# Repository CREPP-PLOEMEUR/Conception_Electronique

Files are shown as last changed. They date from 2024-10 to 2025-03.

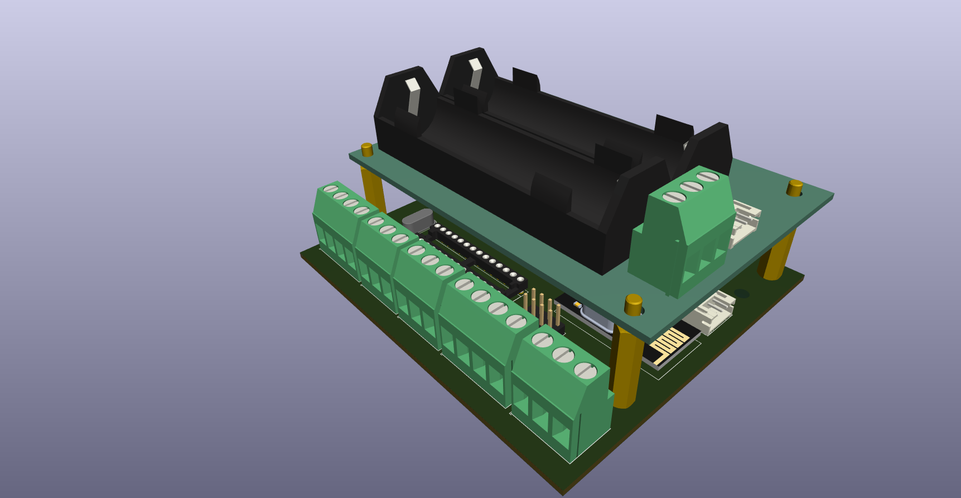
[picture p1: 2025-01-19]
Base.png

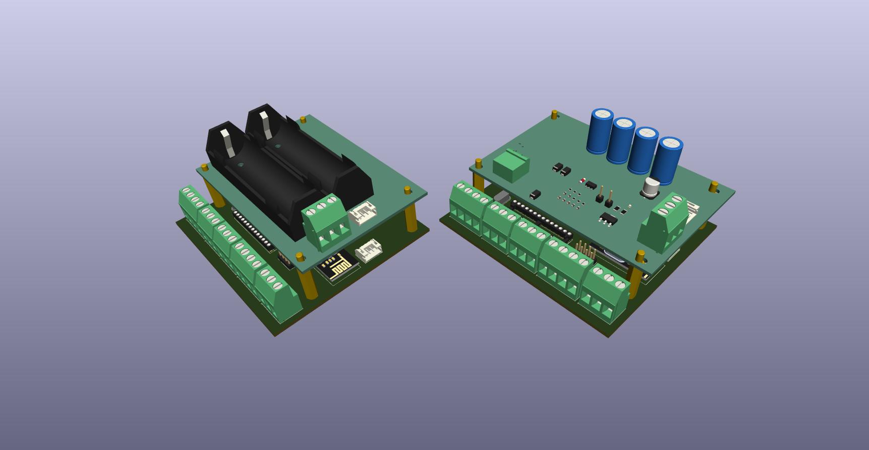
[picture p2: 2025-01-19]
Base.jpg

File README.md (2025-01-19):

# Conception_Electronique
Le répertoire avec les sources de l'atelier Conception Electronique

## Installation de Kicad

La version de Kicad sera la version 8.X : 

## Projets 2024-2025

Pour cette année, les projets souhaités sont :

- Une station météo
- Une carte de développement pour microcontrôleur 

- Cahier des charges
- Schématique
- Commande de matériel
- Affectation des empreintes
- Routage
- Génération du dossier de fabrication
- Montage
- Debug

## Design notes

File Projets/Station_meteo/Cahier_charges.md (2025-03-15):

# Capteurs

- Kit de capteurs sur Internet 

    - Température     (BME280)  -
    - pression          
    - Humidité
    - Vitesse du vent
    - Direction du vent 
    - Pluviométrie (volume)
    - Position GPS - NEO-M6
    - RTC - DS3231

- Connecteurs : 

- USB-C
- LED 
- Bouton Reset

- Connecteur 5 points
- Connecteur 4 points
- Connecteur 3 points
- Connecteur 2 points

Liste du matériel : 

- Borniers 5.08mm
- Microcontrolleur ATMEGA328-PU
- Transistor FDS4559

Options :  - Ensoleillement (GUVA-S12SD)
           - (Détecteur de particule fine (Co2))

- Type de connecteurs capteurs : bornier 5.08mm à vis 

- Intégration de l'antenne du NRF24 (support mécanique à prévoir si module avec ampli)
- doubler eventuellement les cellules lithium

- Mesure du vent :

Mesure du vent toutes les 10 minutes (réveil périodique) puis envoi toutes les 30 minutes
- Potentiomètre pour période de réveil
- Envoi de données "exceptionnelles" lors de rafale

- Envoi de la valeur moyenne et de la rafale

Pour la rafale, mesure avec un compteur à creuser et à designer :

Dimensionnement du pluviomètre  (mesure de volume et de pluie par jour)

Max : 95 mm/h de précipitation

# Alimentation

-> Autonome : 
    - supercondensateurs -> GEstion energie
    - batterie lithium  -> GEstion energie

# Fonctions

- Envoi de données par la station -> traitement des données ailleurs 
- Connecteur d'alimentation de debug : 
    - Shield avec OLED, USB et LED

- Alimentation et panneau solaire : Olivier et Michel H

- Capteurs : Michel O (& Nicolas) Eric (Olivier)

- Microcontroleur et NFR24 : Nicolas & Robin P.

- protocole de communication : Nathalie - (Philippe P)

- 

- PCB : Michel O. (Patrice G). - Philippe C.

- Programmation : Nicolas

- Centralisation des achats et matériel : Guy et Patrick

Faire un point tous les 15 jours à la louche

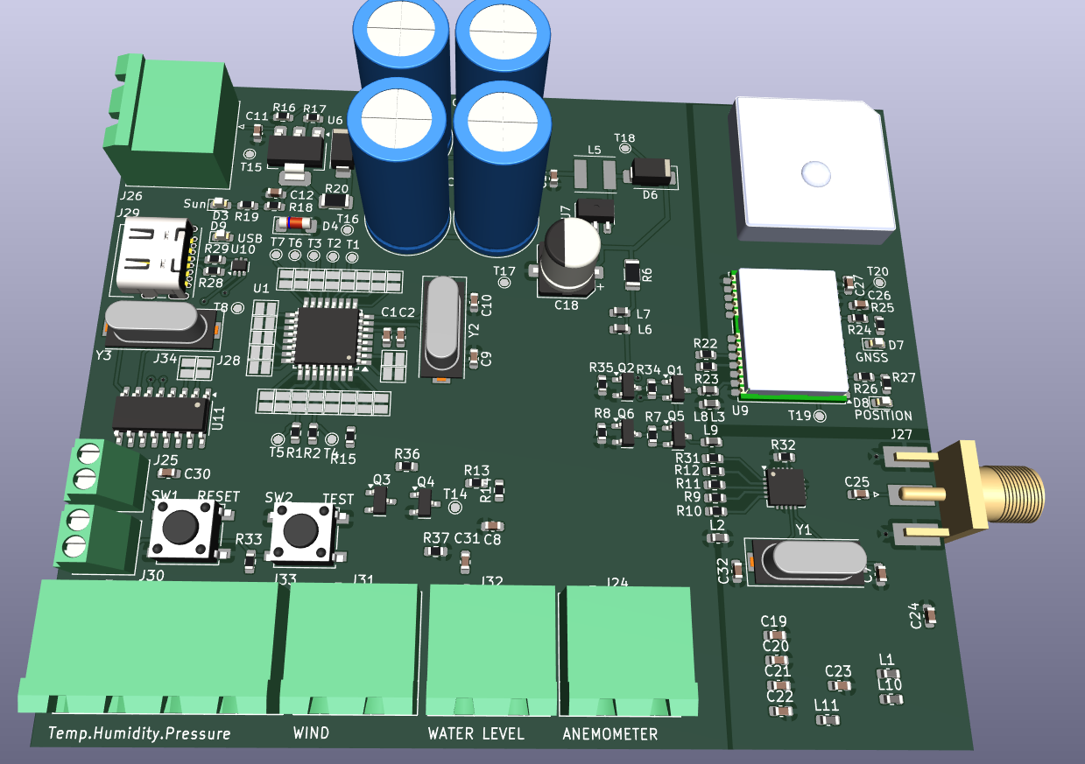
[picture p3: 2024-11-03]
Projets/Station_meteo/PCB/V0_Prototype/img/Proto.png

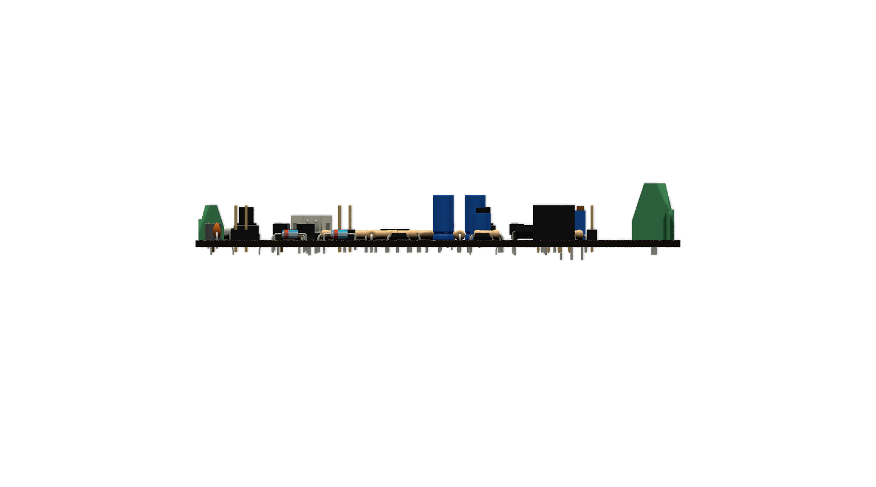
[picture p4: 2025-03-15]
Projets/Station_meteo/PCB/V1_THT/Base/3D_Gallery/Side.png

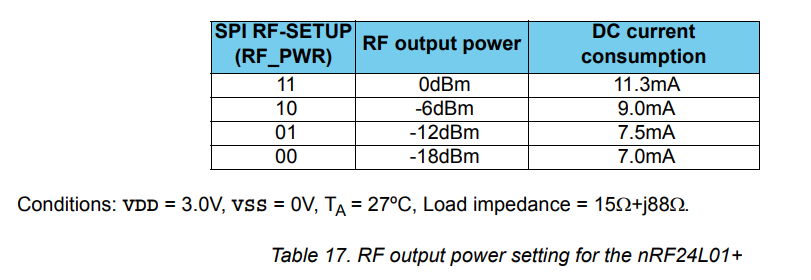
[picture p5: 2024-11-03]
Projets/Station_meteo/Consumption.png

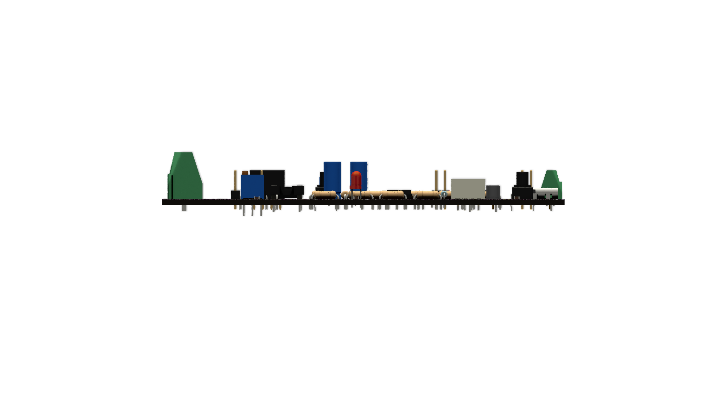
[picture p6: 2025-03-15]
Projets/Station_meteo/PCB/V1_THT/Base/3D_Gallery/Front.png

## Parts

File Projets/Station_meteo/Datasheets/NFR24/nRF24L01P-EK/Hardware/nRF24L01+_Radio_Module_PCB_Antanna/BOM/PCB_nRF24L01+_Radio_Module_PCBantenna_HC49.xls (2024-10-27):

Part | Designator | Footprint | Description
22pF | C1 | 0402 | NPO, +/- 5%, 50V
22pF | C2 | 0402 | NPO, +/- 5%, 50V
2.2nF | C3 | 0402 | X7R, +/- 10%, 50V
4.7pF | C4 | 0402 | NPO, +/- 0.25 pF, 50V
1.5pF | C5 | 0402 | NPO, +/- 0.1 pF, 50V
1.0pF | C6 | 0402 | NPO, +/- 0.1 pF, 50V
33nF | C7 | 0402 | X7R, +/- 10%, 50V
1nF | C8 | 0402 | X7R, +/- 10%, 50V
10nF | C9 | 0402 | X7R, +/- 10%, 50V
CON8 | J1 | 2,54mm pitch
8.2nH | L1 | 0402 | chip inductor +/- 5%
2.7nH | L2 | 0402 | chip inductor +/- 5%
3.9nH | L3 | 0402 | chip inductor +/- 5%
1M | R1 | 0402 | +/-5% (or better)
22K | R2 | 0402 | +/- 1 %
nRF24L01+ | U1 | QFN20L/5x5
16MHz | X1 | HC49 | Total tolerence +/-60ppm, CL=12pF

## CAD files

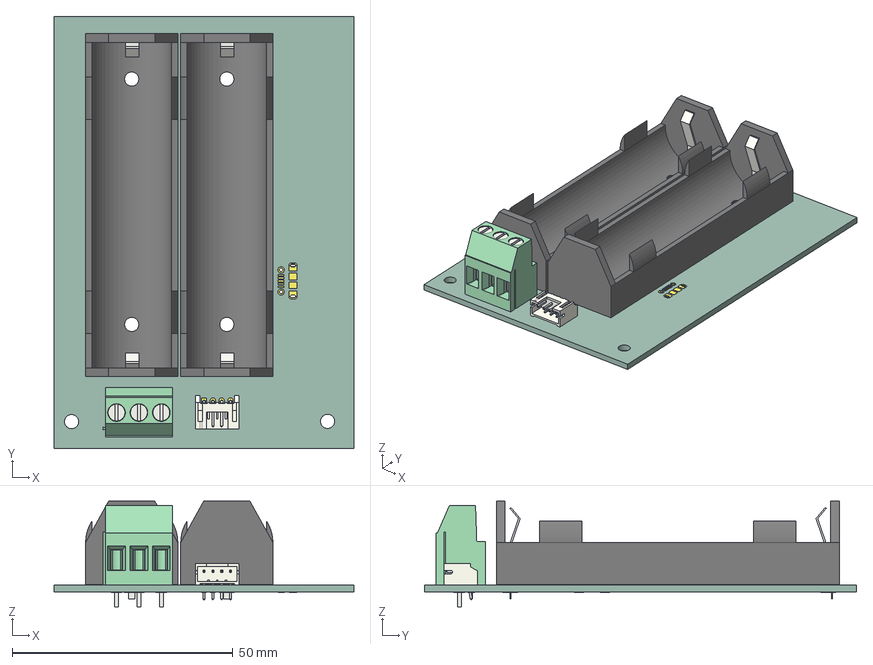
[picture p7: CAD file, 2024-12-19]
Projets/Station_meteo/PCB/V1_THT/Shield_Lithium/Tracker.step
67.9 x 97.9 x 24.0 mm
MPD_BH_18650_PC2 x 2
JST_S4B_PH_K
TerminalBlock_Phoenix_MKDS_3_3_508_1x03_P508mm_Horizontal
Shield_Lithium_pad_1
Shield_Lithium_pad_2
Shield_Lithium_pad_3
Shield_Lithium_pad_4
Shield_Lithium_pad_5
Shield_Lithium_pad_6
Shield_Lithium_pad_7
Shield_Lithium_pad_8
Shield_Lithium_pad_9
Shield_Lithium_pad_10
Shield_Lithium_pad_11
Shield_Lithium_pad_12
Shield_Lithium_pad_13
Shield_Lithium_pad_14
Shield_Lithium_pad_15
Shield_Lithium_pad_16
Shield_Lithium_pad_17
Shield_Lithium_pad_18
Shield_Lithium_pad_19
Shield_Lithium_pad_20
Shield_Lithium_pad_21
Shield_Lithium_pad_22
Shield_Lithium_pad_23
Shield_Lithium_pad_24
Shield_Lithium_pad_25
Shield_Lithium_pad_26
Shield_Lithium_pad_27
Shield_Lithium_pad_28
Shield_Lithium_pad_29
Shield_Lithium_pad_30
Shield_Lithium_pad_31
Shield_Lithium_pad_32
Shield_Lithium_pad_33
Shield_Lithium_pad_34
Shield_Lithium_pad_35
Shield_Lithium_pad_36
Shield_Lithium_pad_37
Shield_Lithium_pad_38
Shield_Lithium_pad_39
Shield_Lithium_pad_40
Shield_Lithium_pad_41
Shield_Lithium_pad_42
Shield_Lithium_pad_43
Shield_Lithium_pad_44
Shield_Lithium_pad_45
Shield_Lithium_pad_46
Shield_Lithium_pad_47
Shield_Lithium_pad_48
Shield_Lithium_pad_49
Shield_Lithium_pad_50
Shield_Lithium_pad_51
Shield_Lithium_pad_52
Shield_Lithium_pad_53
Shield_Lithium_pad_54
Shield_Lithium_pad_55
Shield_Lithium_pad_56
Shield_Lithium_pad_57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

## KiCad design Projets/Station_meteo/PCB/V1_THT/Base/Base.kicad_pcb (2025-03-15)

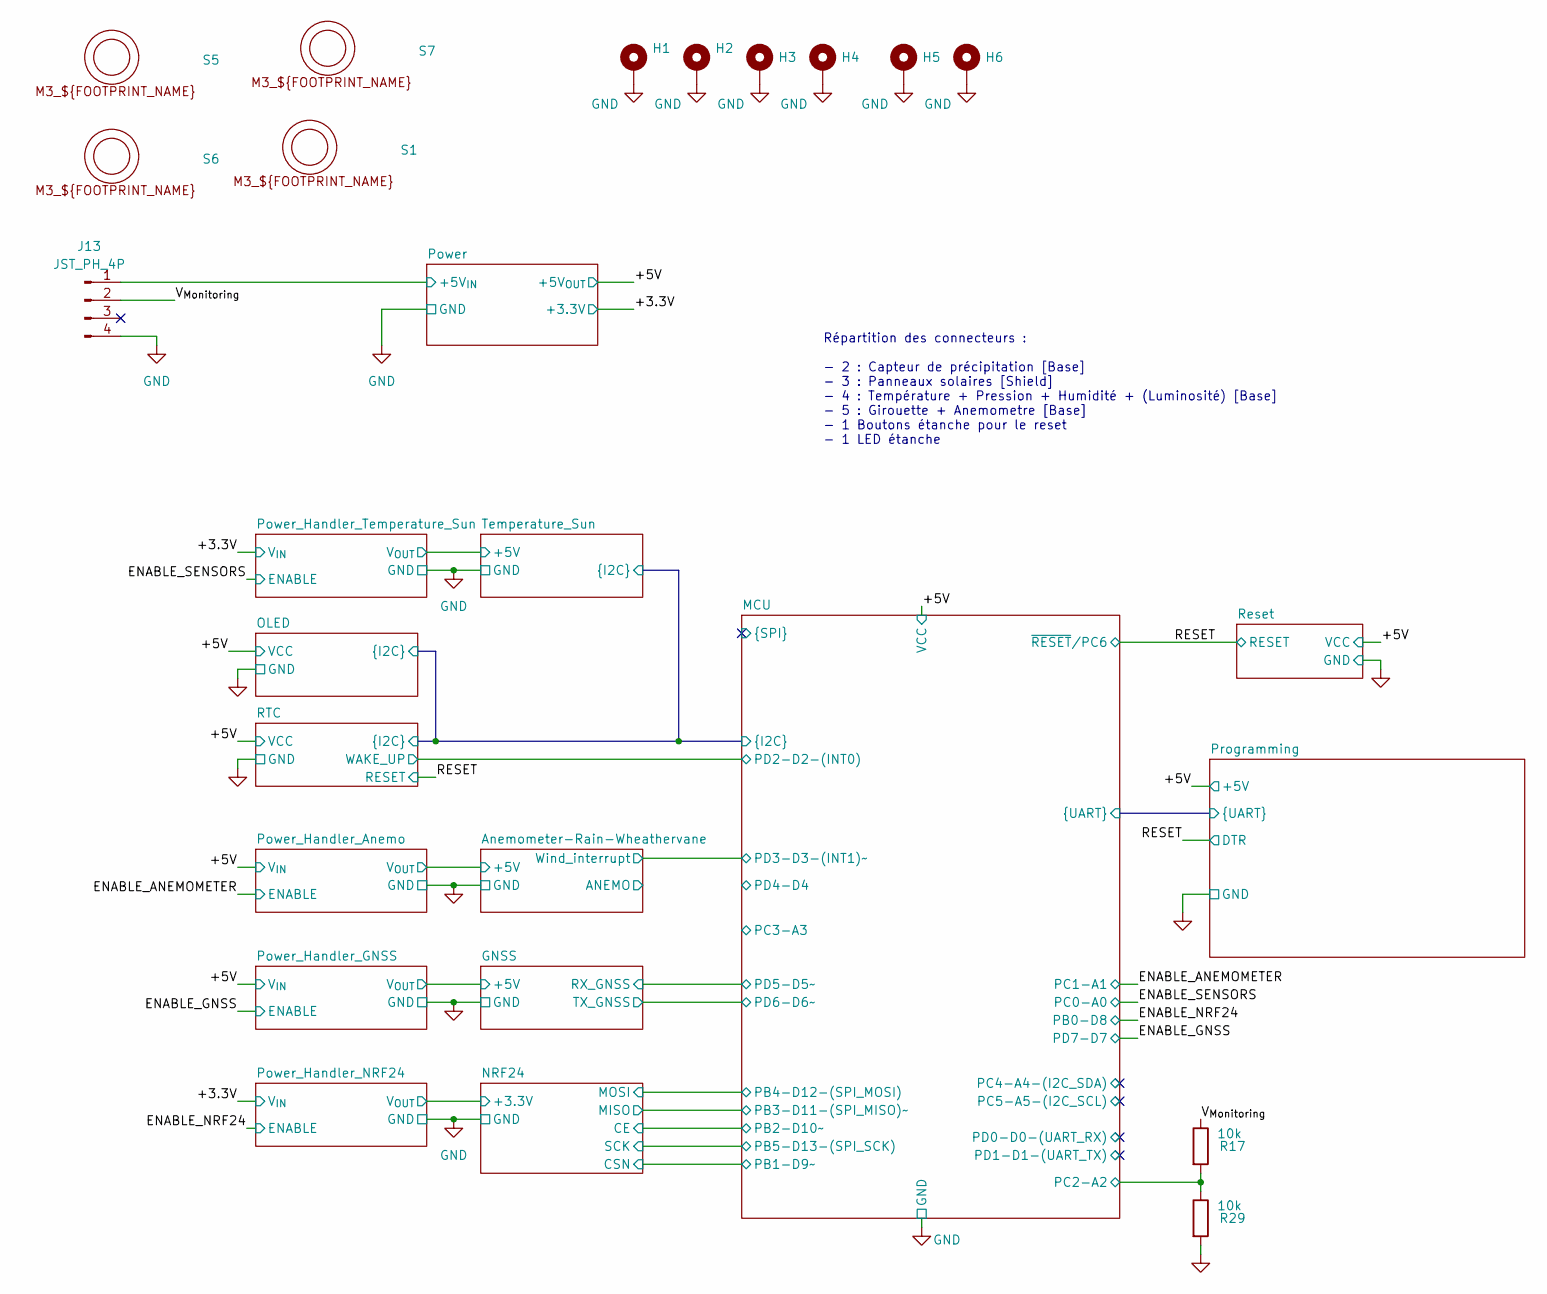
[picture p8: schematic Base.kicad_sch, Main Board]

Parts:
H1, H2, H3, H4, H5, H6: MountingHole_Pad; MountingHole_3.2mm_M3
J13: JST_PH_4P; JST_PH_B4B-PH-K_1x04_P2.00mm_Vertical
R17, R29: 10k; R_Axial_DIN0207_L6.3mm_D2.5mm_P7.62mm_Horizontal
S1, S5, S6, S7: Spacer_M3_MF_05mm

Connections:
/MCU/PC2-A2: R17.2, R29.1; also elsewhere on the board
/Power/+5V_{IN}: J13.1; also elsewhere on the board
/V_{Monitoring}: J13.2, R17.1
GND: H1.1, H2.1, H3.1, H4.1, H5.1, H6.1, J13.4, R29.2; also elsewhere on the board

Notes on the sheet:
Répartition des connecteurs : - 2 : Capteur de précipitation [Base] - 3 : Panneaux solaires [Shield] - 4 : Température + Pression + Humidité + (Luminosité) [Base] - 5 : Girouette + Anemometre [Base] - 1 Boutons étanche pour le reset - 1 LED étanche

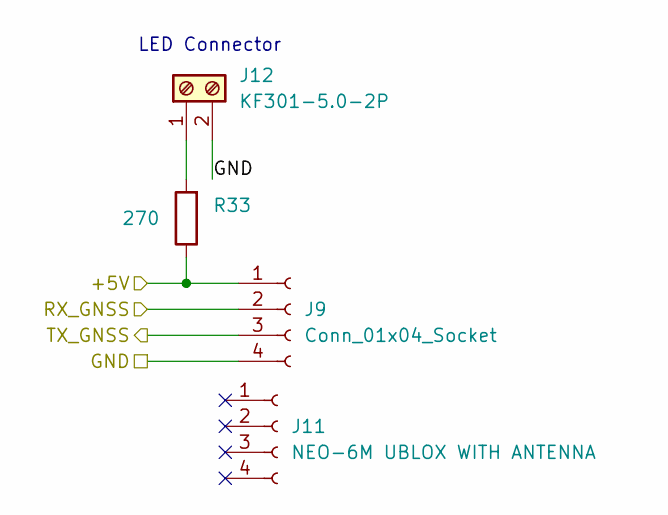
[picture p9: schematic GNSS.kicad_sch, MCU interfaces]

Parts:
J9: Conn_01x04_Socket; PinSocket_1x04_P2.54mm_Vertical
J11: NEO-6M UBLOX WITH ANTENNA; PinSocket_1x04_P2.54mm_Vertical
J12: KF301-5.0-2P; TerminalBlock_Phoenix_MKDS-1,5-2_1x02_P5.00mm_Horizontal
R33: 270; R_Axial_DIN0207_L6.3mm_D2.5mm_P7.62mm_Horizontal

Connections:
/GNSS/+5V: J9.1, R33.1; also elsewhere on the board
/GNSS/RX_GNSS: J9.2; also elsewhere on the board
/GNSS/TX_GNSS: J9.3; also elsewhere on the board
GND: J9.4, J12.2; also elsewhere on the board
unnamed: J12.1, R33.2

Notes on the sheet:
LED Connector

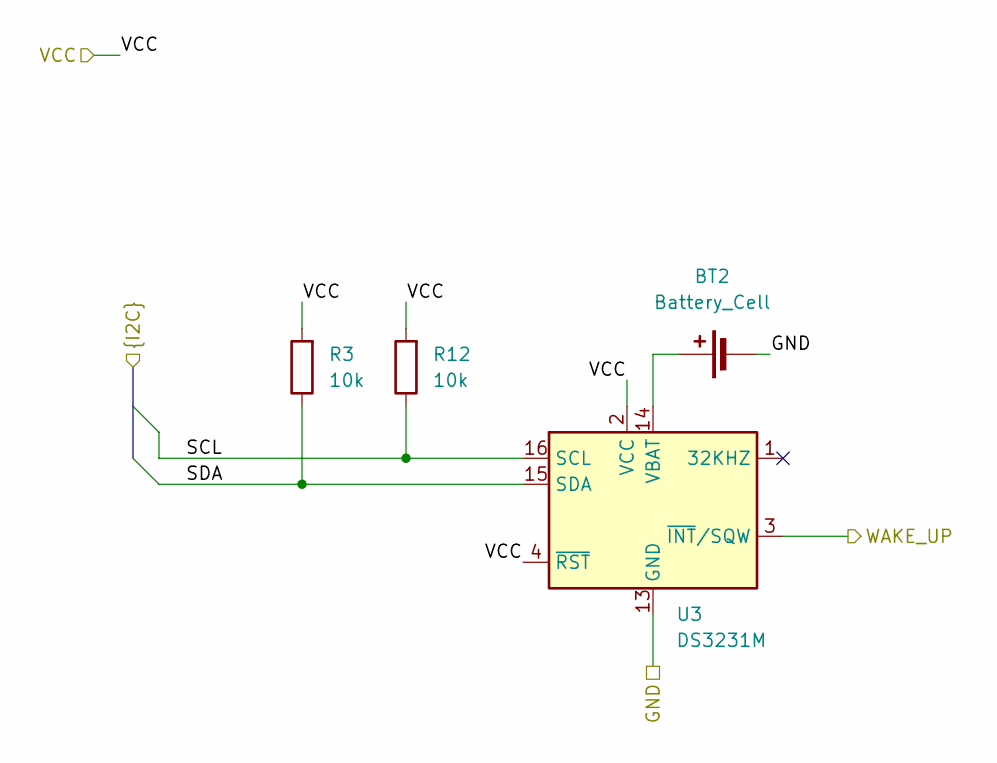
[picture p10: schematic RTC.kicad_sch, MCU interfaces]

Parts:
BT2: Battery_Cell; MPD_BC501SM-TR
R3, R12: 10k; R_Axial_DIN0207_L6.3mm_D2.5mm_P7.62mm_Horizontal
U3: DS3231M; SOIC-16W_7.5x10.3mm_P1.27mm

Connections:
/MCU/PD2-D2-(INT0): U3.3 (~INT/SQW); also elsewhere on the board
/MCU/SCL: R12.1, U3.16 (SCL); also elsewhere on the board
/MCU/SDA: R3.1, U3.15 (SDA); also elsewhere on the board
GND: U3.5 (GND), U3.6 (GND), U3.7 (GND), U3.8 (GND), U3.9 (GND), U3.10 (GND), U3.11 (GND), U3.12 (GND), U3.13 (GND); also elsewhere on the board
unnamed: BT2.1 (+), U3.14 (VBAT)
unnamed 75: R3.1; also elsewhere on the board
unnamed 76: R12.1; also elsewhere on the board
unnamed 77: R3.2, R12.2; also elsewhere on the board

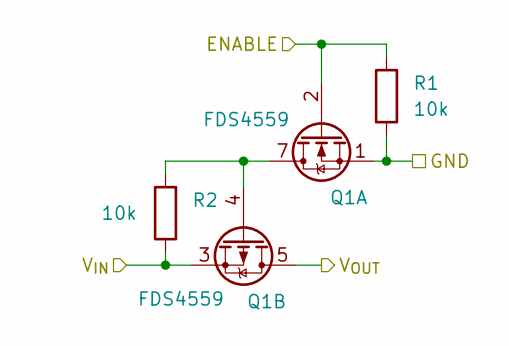
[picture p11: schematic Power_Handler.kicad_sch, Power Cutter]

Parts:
Q1: FDS4559; SOIC-8_3.9x4.9mm_P1.27mm
R1, R2: 10k; R_Axial_DIN0207_L6.3mm_D2.5mm_P7.62mm_Horizontal

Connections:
/Anemometer-Rain-Wheathervane/+5V: Q1.5 (D), Q1.6 (D); also elsewhere on the board
/ENABLE_ANEMOMETER: Q1.2 (G), R1.2; also elsewhere on the board
GND: Q1.1 (S), R1.1; also elsewhere on the board
unnamed: Q1.4 (G), Q1.7 (D), Q1.8 (D), R2.2

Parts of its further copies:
Q2, Q3, Q4: FDS4559; SOIC-8_3.9x4.9mm_P1.27mm
R14, R15, R16, R18, R19, R28: 10k; R_Axial_DIN0207_L6.3mm_D2.5mm_P7.62mm_Horizontal

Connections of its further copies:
/+3.3V: Q2.3 (1), Q4.3 (1), R18.1, R28.1; also elsewhere on the board
/ENABLE_GNSS: Q3.2 (G), R15.2; also elsewhere on the board
/ENABLE_NRF24: Q2.2 (G), R14.2; also elsewhere on the board
/ENABLE_SENSORS: Q4.2 (G), R16.2; also elsewhere on the board
/GNSS/+5V: Q3.5 (D), Q3.6 (D); also elsewhere on the board
/NRF24/+3.3V: Q2.5 (D), Q2.6 (D); also elsewhere on the board
/Power_Handler_Temperature_Sun/V_{OUT}: Q4.5 (D), Q4.6 (D)
GND: Q2.1 (S), Q3.1 (S), Q4.1 (S), R14.1, R15.1, R16.1; also elsewhere on the board
unnamed: Q2.4 (G), Q2.7 (D), Q2.8 (D), R18.2
unnamed: Q3.4 (G), Q3.7 (D), Q3.8 (D), R19.2
unnamed: Q4.4 (G), Q4.7 (D), Q4.8 (D), R28.2

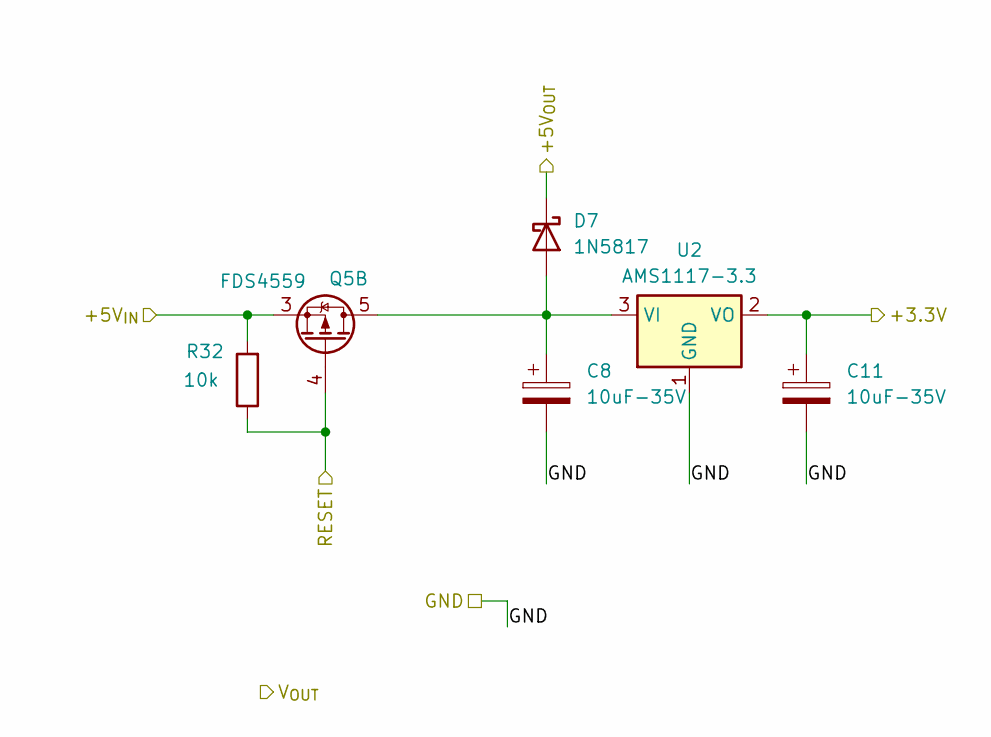
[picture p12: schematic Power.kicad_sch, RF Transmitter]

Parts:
C8, C11: 10uF-35V; C_Radial_D5.0mm_H11.0mm_P2.00mm
D7: 1N5817; D_DO-41_SOD81_P10.16mm_Horizontal
Q5: FDS4559; SOIC-8_3.9x4.9mm_P1.27mm
R32: 10k; R_Axial_DIN0207_L6.3mm_D2.5mm_P7.62mm_Horizontal
U2: AMS1117-3.3; SOT-223-3_TabPin2

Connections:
/+3.3V: C11.1, U2.2 (VO); also elsewhere on the board
/Power/+5V_{IN}: Q5.3 (1), R32.2; also elsewhere on the board
/Power/RESET: Q5.4 (G), R32.1
GND: C8.2, C11.2, U2.1 (GND); also elsewhere on the board
unnamed: C8.1, D7.2 (A), Q5.5 (D), Q5.6 (D), U2.3 (VI)

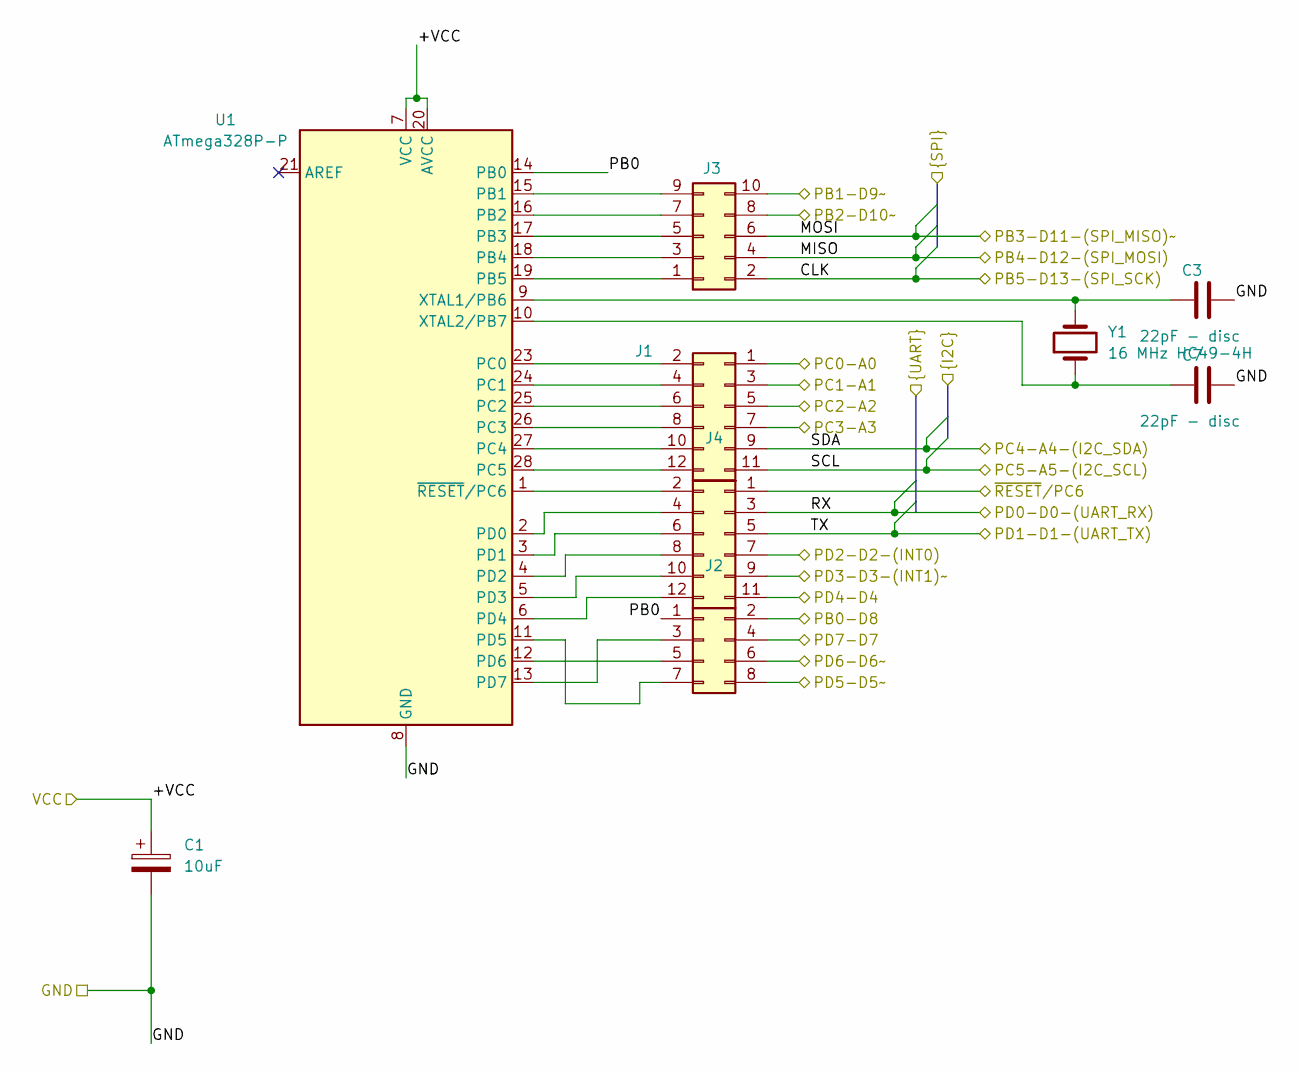
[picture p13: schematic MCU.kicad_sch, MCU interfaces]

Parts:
C1: 10uF; C_Radial_D5.0mm_H11.0mm_P2.00mm
C3, C7: 22pF - disc; C_Disc_D4.3mm_W1.9mm_P5.00mm
J1: Conn_02x05_Odd_Even; PinHeader_2x05_P2.54mm_Vertical
J2: Conn_02x04_Odd_Even; PinHeader_2x04_P2.54mm_Vertical
J3, J4: Conn_02x06_Odd_Even; PinHeader_2x06_P2.54mm_Vertical
U1: ATmega328P-P; DIP-28_W7.62mm_Socket
Y1: 16 MHz HC49-4H; Crystal_HC49-4H_Vertical

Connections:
/Anemometer-Rain-Wheathervane/Wind_interrupt: J4.9; also elsewhere on the board
/ENABLE_ANEMOMETER: J3.3; also elsewhere on the board
/ENABLE_GNSS: J2.4; also elsewhere on the board
/ENABLE_NRF24: J2.2; also elsewhere on the board
/ENABLE_SENSORS: J3.1; also elsewhere on the board
/GNSS/RX_GNSS: J2.8; also elsewhere on the board
/GNSS/TX_GNSS: J2.6; also elsewhere on the board
/MCU/CLK: J1.2; also elsewhere on the board
/MCU/MISO: J1.4; also elsewhere on the board
/MCU/MOSI: J1.6; also elsewhere on the board
/MCU/PB0: J2.1, U1.14 (PB0)
/MCU/PB1-D9~: J1.10; also elsewhere on the board
/MCU/PB2-D10~: J1.8; also elsewhere on the board
/MCU/PC2-A2: J3.5; also elsewhere on the board
/MCU/PC3-A3: J3.7
/MCU/PD2-D2-(INT0): J4.7; also elsewhere on the board
/MCU/PD4-D4: J4.11
/MCU/RX: J4.3; also elsewhere on the board
/MCU/SCL: J3.11; also elsewhere on the board
/MCU/SDA: J3.9; also elsewhere on the board
/MCU/TX: J4.5; also elsewhere on the board
GND: C1.2, C3.2, C7.2, U1.8 (GND), U1.22 (GND); also elsewhere on the board
unnamed: J1.1, U1.19 (PB5)
unnamed: J1.3, U1.18 (PB4)
unnamed: J1.5, U1.17 (PB3)
unnamed: J1.7, U1.16 (PB2)
unnamed: J1.9, U1.15 (PB1)
unnamed: J2.3, U1.13 (PD7)
unnamed: J2.5, U1.12 (PD6)
unnamed: J2.7, U1.11 (PD5)
unnamed: J3.2, U1.23 (PC0)
unnamed: J3.4, U1.24 (PC1)
unnamed: J3.6, U1.25 (PC2)
unnamed: J3.8, U1.26 (PC3)
unnamed: J3.10, U1.27 (PC4)
unnamed: J3.12, U1.28 (PC5)
unnamed: J4.2, U1.1 (~RESET/PC6)
unnamed: J4.4, U1.2 (PD0)
unnamed: J4.6, U1.3 (PD1)
unnamed: J4.8, U1.4 (PD2)
unnamed: J4.10, U1.5 (PD3)
unnamed: J4.12, U1.6 (PD4)
unnamed: C3.1, U1.9 (XTAL1/PB6), Y1.2
unnamed: C7.1, U1.10 (XTAL2/PB7), Y1.1

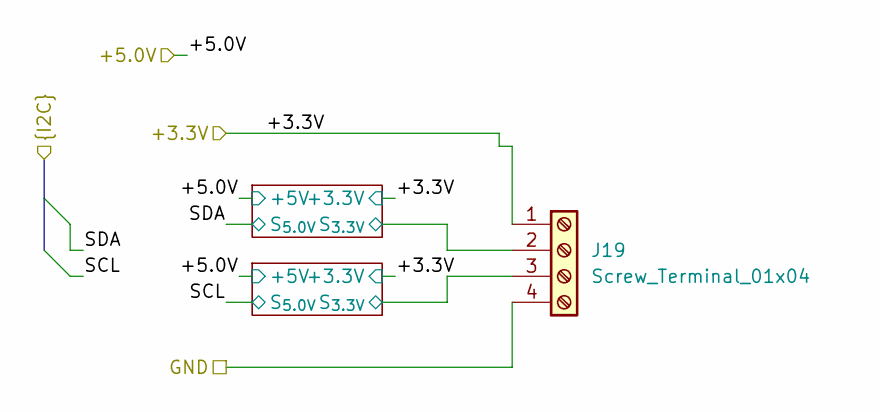
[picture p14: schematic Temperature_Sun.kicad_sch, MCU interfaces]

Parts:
J19: Screw_Terminal_01x04; TerminalBlock_Phoenix_MKDS-1,5-4-5.08_1x04_P5.08mm_Horizont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

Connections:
/Temperature_Sun/+3.3V: J19.1; also elsewhere on the board
/Temperature_Sun/Translator1/S_{3.3V}: J19.3; also elsewhere on the board
/Temperature_Sun/Translator/S_{3.3V}: J19.2; also elsewhere on the board
GND: J19.4; also elsewhere on the board

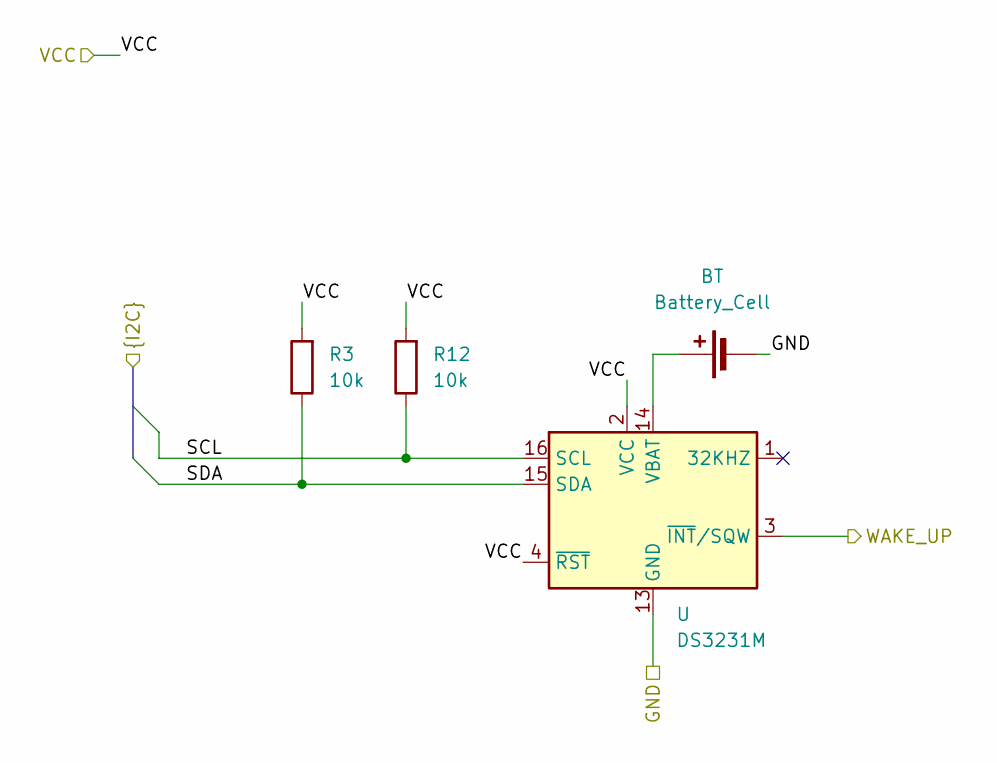
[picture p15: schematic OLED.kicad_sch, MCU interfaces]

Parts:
BT: Battery_Cell; MPD_BC501SM-TR
R3, R12: 10k; R_Axial_DIN0207_L6.3mm_D2.5mm_P7.62mm_Horizontal
U: DS3231M; SOIC-16W_7.5x10.3mm_P1.27mm

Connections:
/MCU/SCL: R12.1; also elsewhere on the board
/MCU/SDA: R3.1; also elsewhere on the board
unnamed: BT.1 (+), U.14 (VBAT)
unnamed: R3.1, U.15 (SDA)
unnamed: R12.1, U.16 (SCL)
unnamed: R3.2, R12.2, U.2 (VCC), U.4 (~RST)
unnamed: U.5 (GND), U.6 (GND), U.7 (GND), U.8 (GND), U.9 (GND), U.10 (GND), U.11 (GND), U.12 (GND), U.13 (GND)

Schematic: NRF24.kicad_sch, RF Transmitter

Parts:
U8: NRF24L01_Breakout; nRF24L01_Breakout

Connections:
/MCU/MOSI: U8.7 (MISO); also elsewhere on the board
/NRF24/+3.3V: U8.2 (VCC); also elsewhere on the board
/NRF24/Bridge1/OUT: U8.6 (MOSI); also elsewhere on the board
/NRF24/Bridge2/OUT: U8.4 (~CSN); also elsewhere on the board
/NRF24/Bridge3/OUT: U8.3 (CE); also elsewhere on the board
/NRF24/Bridge/OUT: U8.5 (SCK); also elsewhere on the board
GND: U8.1 (GND); also elsewhere on the board

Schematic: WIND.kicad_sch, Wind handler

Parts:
C4, C6: 100nF; C_0603_1608Metric
C5: 10uF; C_Radial_D5.0mm_H11.0mm_P2.00mm
D1: LED; LED_D3.0mm
D8: 1N5817; D_DO-41_SOD81_P10.16mm_Horizontal
J5: KF301-5.0-2P; TerminalBlock_Phoenix_MKDS-1,5-2_1x02_P5.00mm_Horizontal
J6: Conn_01x03_Pin; PinHeader_1x03_P2.54mm_Vertical
J20: Screw_Terminal_01x04; TerminalBlock_Phoenix_MKDS-1,5-4-5.08_1x04_P5.08mm_Horizont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
JP2: Jumper; PinHeader_1x02_P2.54mm_Vertical
JP3: Jumper_2.54mm_blue
R4: R_10K_SMD_0603; R_0603_1608Metric
R5, R11: 100k; R_Axial_DIN0207_L6.3mm_D2.5mm_P7.62mm_Horizontal
R6, R7, R8, R10: 10k; R_Axial_DIN0207_L6.3mm_D2.5mm_P7.62mm_Horizontal
R9: 270; R_Axial_DIN0207_L6.3mm_D2.5mm_P7.62mm_Horizontal
RV1: R_Potentiometer; Potentiometer_Bourns_3266Y_Vertical
T9, T10, T11: TP; TestPoint_Pad_D1.0mm
U4: LM358; DIP-8_W7.62mm
U5: 74HC123; DIP-16_W7.62mm_Socket

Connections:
/Anemometer-Rain-Wheathervane/+5V: C5.1, R4.1, R5.1, RV1.1, U4.8 (V+), U5.16 (VCC); also elsewhere on the board
/Anemometer-Rain-Wheathervane/Anemo_{signal}: J6.2, T9.1, U5.9 (A)
/Anemometer-Rain-Wheathervane/Wind_interrupt: JP2.1 (A), R7.2, R8.2, U4.7; also elsewhere on the board
GND: C5.2, C6.2, R8.1, R9.2, R11.2, RV1.3, U4.4 (V-), U5.8 (GND), U5.10 (B), U5.11 (Clr); also elsewhere on the board
unnamed: D1.2 (A), JP2.2 (B)
unnamed: D1.1 (K), R9.1
unnamed: J5.1, J6.3, R11.1
unnamed: J5.2, J6.1, R5.2
unnamed: C6.1, R10.2, U4.3 (+)
unnamed: R6.1, T11.1, U4.1, U4.2 (-)
unnamed: R6.2, R7.1, U4.5 (+)
unnamed: RV1.2, U4.6 (-)
unnamed: C4.2, U5.6 (Cext)
unnamed: R10.1, T10.1, U5.5 (Q)
unnamed: C4.1, R4.2, U5.7 (RCext)

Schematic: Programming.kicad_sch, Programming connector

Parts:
C2, C19: 100nF; C_0603_1608Metric
D10: 1N5817; D_DO-41_SOD81_P10.16mm_Horizontal
J8: USB_C_Receptacle; USB_C_Receptacle_GCT_USB4085
J15, J16: SolderJumper_2_Bridged; SolderJumper-2_P1.3mm_Bridged_Pad1.0x1.5mm
U10: CH340G; SOIC-16_3.9x9.9mm_P1.27mm
Y2: Crystal HC49-4H 12 MHz; Crystal_HC49-4H_Vertical

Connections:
/MCU/RX: J15.2 (B); also elsewhere on the board
/MCU/TX: J16.2 (B); also elsewhere on the board
/Programming/D+: J8.A6 (D+), J8.B6 (D+), U10.5 (UD+)
/Programming/D-: J8.A7 (D-), J8.B7 (D-), U10.6 (UD-)
GND: C2.2, J8.A1 (GND), J8.A12 (GND), J8.B1 (GND), J8.B12 (GND), U10.1 (GND); also elsewhere on the board
unnamed: J15.1 (A), U10.2 (TXD)
unnamed: J16.1 (A), U10.3 (RXD)
unnamed: C2.1, U10.4 (V3)
unnamed: U10.7 (XI), Y2.2
unnamed: U10.8 (XO), Y2.1
unnamed: C19.1, U10.13 (~DTR)

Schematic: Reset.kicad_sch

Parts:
R13: 10k; R_Axial_DIN0207_L6.3mm_D2.5mm_P7.62mm_Horizontal
SW1: SW_B; SW_PUSH_6mm_H8mm

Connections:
GND: SW1.1 (A); also elsewhere on the board

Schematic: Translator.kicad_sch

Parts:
R20, R21: 10k; R_Axial_DIN0207_L6.3mm_D2.5mm_P7.62mm_Horizontal

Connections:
/MCU/MISO: R20.1; also elsewhere on the board
/NRF24/Bridge1/OUT: R20.2, R21.1; also elsewhere on the board
GND: R21.2; also elsewhere on the board

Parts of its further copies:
R22, R23, R24, R25, R26, R27, R34, R35: 10k; R_Axial_DIN0207_L6.3mm_D2.5mm_P7.62mm_Horizontal

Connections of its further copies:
/MCU/CLK: R22.1; also elsewhere on the board
/MCU/PB1-D9~: R24.1; also elsewhere on the board
/MCU/PB2-D10~: R26.1; also elsewhere on the board
/MCU/SDA: R34.2; also elsewhere on the board
/NRF24/Bridge2/OUT: R24.2, R25.1; also elsewhere on the board
/NRF24/Bridge3/OUT: R26.2, R27.1; also elsewhere on the board
/NRF24/Bridge/OUT: R22.2, R23.1; also elsewhere on the board
/Temperature_Sun/+3.3V: R35.1; also elsewhere on the board
/Temperature_Sun/+5.0V: R34.1; also elsewhere on the board
/Temperature_Sun/Translator/S_{3.3V}: R35.2; also elsewhere on the board
GND: R23.2, R25.2, R27.2; also elsewhere on the board

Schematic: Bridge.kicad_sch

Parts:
R20, R21: 10k; R_Axial_DIN0207_L6.3mm_D2.5mm_P7.62mm_Horizontal

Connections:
/MCU/MISO: R20.1; also elsewhere on the board
/NRF24/Bridge1/OUT: R20.2, R21.1; also elsewhere on the board
GND: R21.2; also elsewhere on the board

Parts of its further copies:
R22, R23, R24, R25, R26, R27: 10k; R_Axial_DIN0207_L6.3mm_D2.5mm_P7.62mm_Horizontal

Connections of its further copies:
/MCU/CLK: R22.1; also elsewhere on the board
/MCU/PB1-D9~: R24.1; also elsewhere on the board
/MCU/PB2-D10~: R26.1; also elsewhere on the board
/NRF24/Bridge2/OUT: R24.2, R25.1; also elsewhere on the board
/NRF24/Bridge3/OUT: R26.2, R27.1; also elsewhere on the board
/NRF24/Bridge/OUT: R22.2, R23.1; also elsewhere on the board
GND: R23.2, R25.2, R27.2; also elsewhere on the board

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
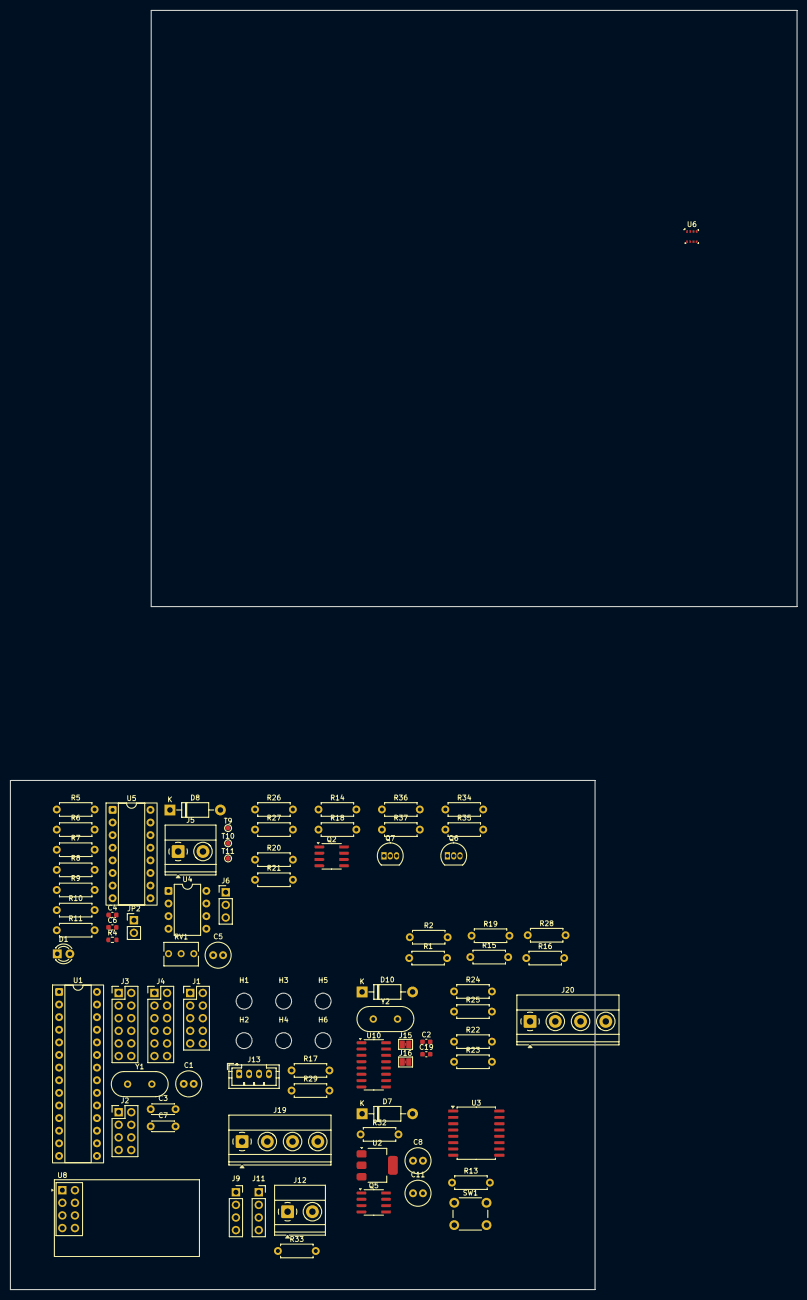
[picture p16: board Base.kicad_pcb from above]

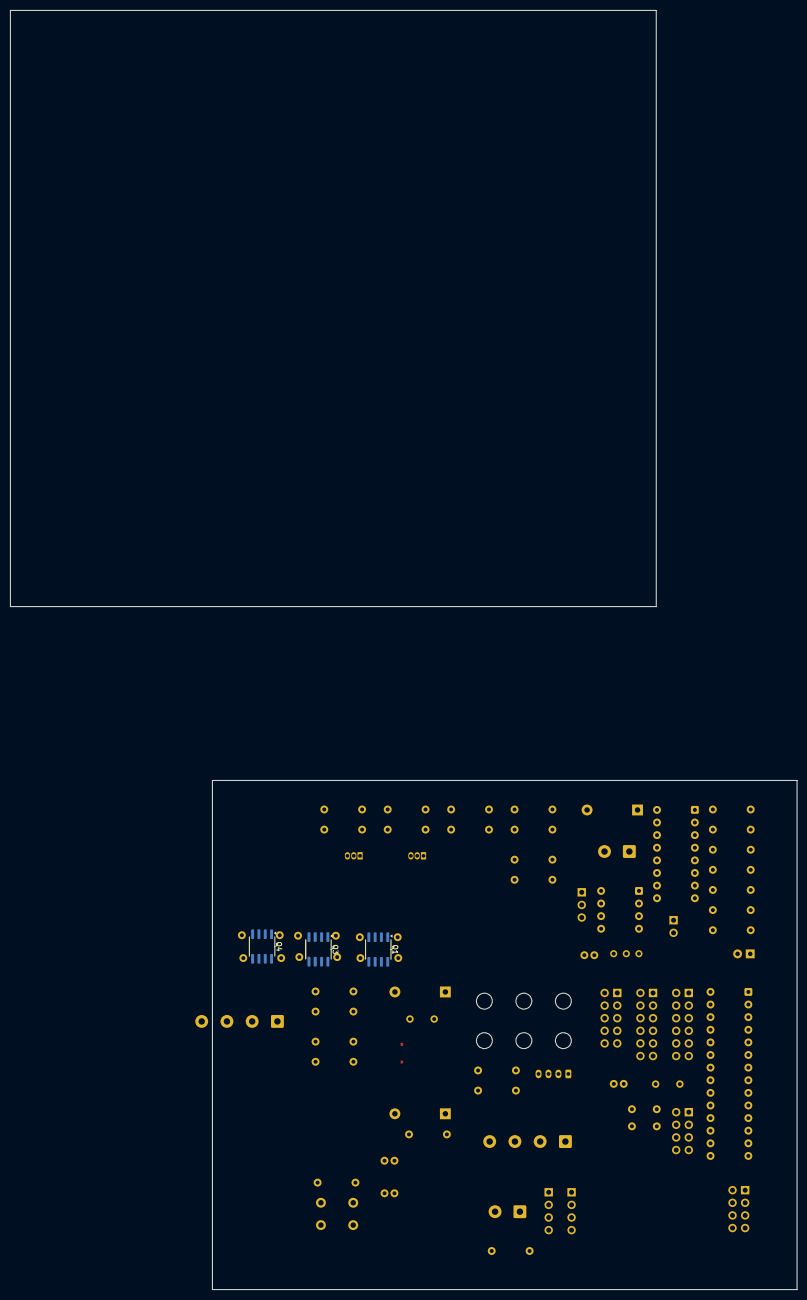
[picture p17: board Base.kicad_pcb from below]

Board: 2 copper layers, 117.7 x 102.5 mm, 96 parts (3 on the bottom side), 84 nets.

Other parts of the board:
Q6, Q7: 2N7000; TO-92_Inline
R36, R37: 10k; R_Axial_DIN0207_L6.3mm_D2.5mm_P7.62mm_Horizontal
STACKUP1: (no value)
U6: BME280; Bosch_LGA-8_2.5x2.5mm_P0.65mm_ClockwisePinNumbering

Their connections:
/MCU/SCL: Q7.3 (D), R37.2; also elsewhere on the board
/MCU/SDA: Q6.3 (D); also elsewhere on the board
/Temperature_Sun/+3.3V: Q6.2 (G), Q7.2 (G), R36.1; also elsewhere on the board
/Temperature_Sun/+5.0V: R37.1; also elsewhere on the board
/Temperature_Sun/Translator1/S_{3.3V}: Q7.1 (S), R36.2; also elsewhere on the board
/Temperature_Sun/Translator/S_{3.3V}: Q6.1 (S); also elsewhere on the board

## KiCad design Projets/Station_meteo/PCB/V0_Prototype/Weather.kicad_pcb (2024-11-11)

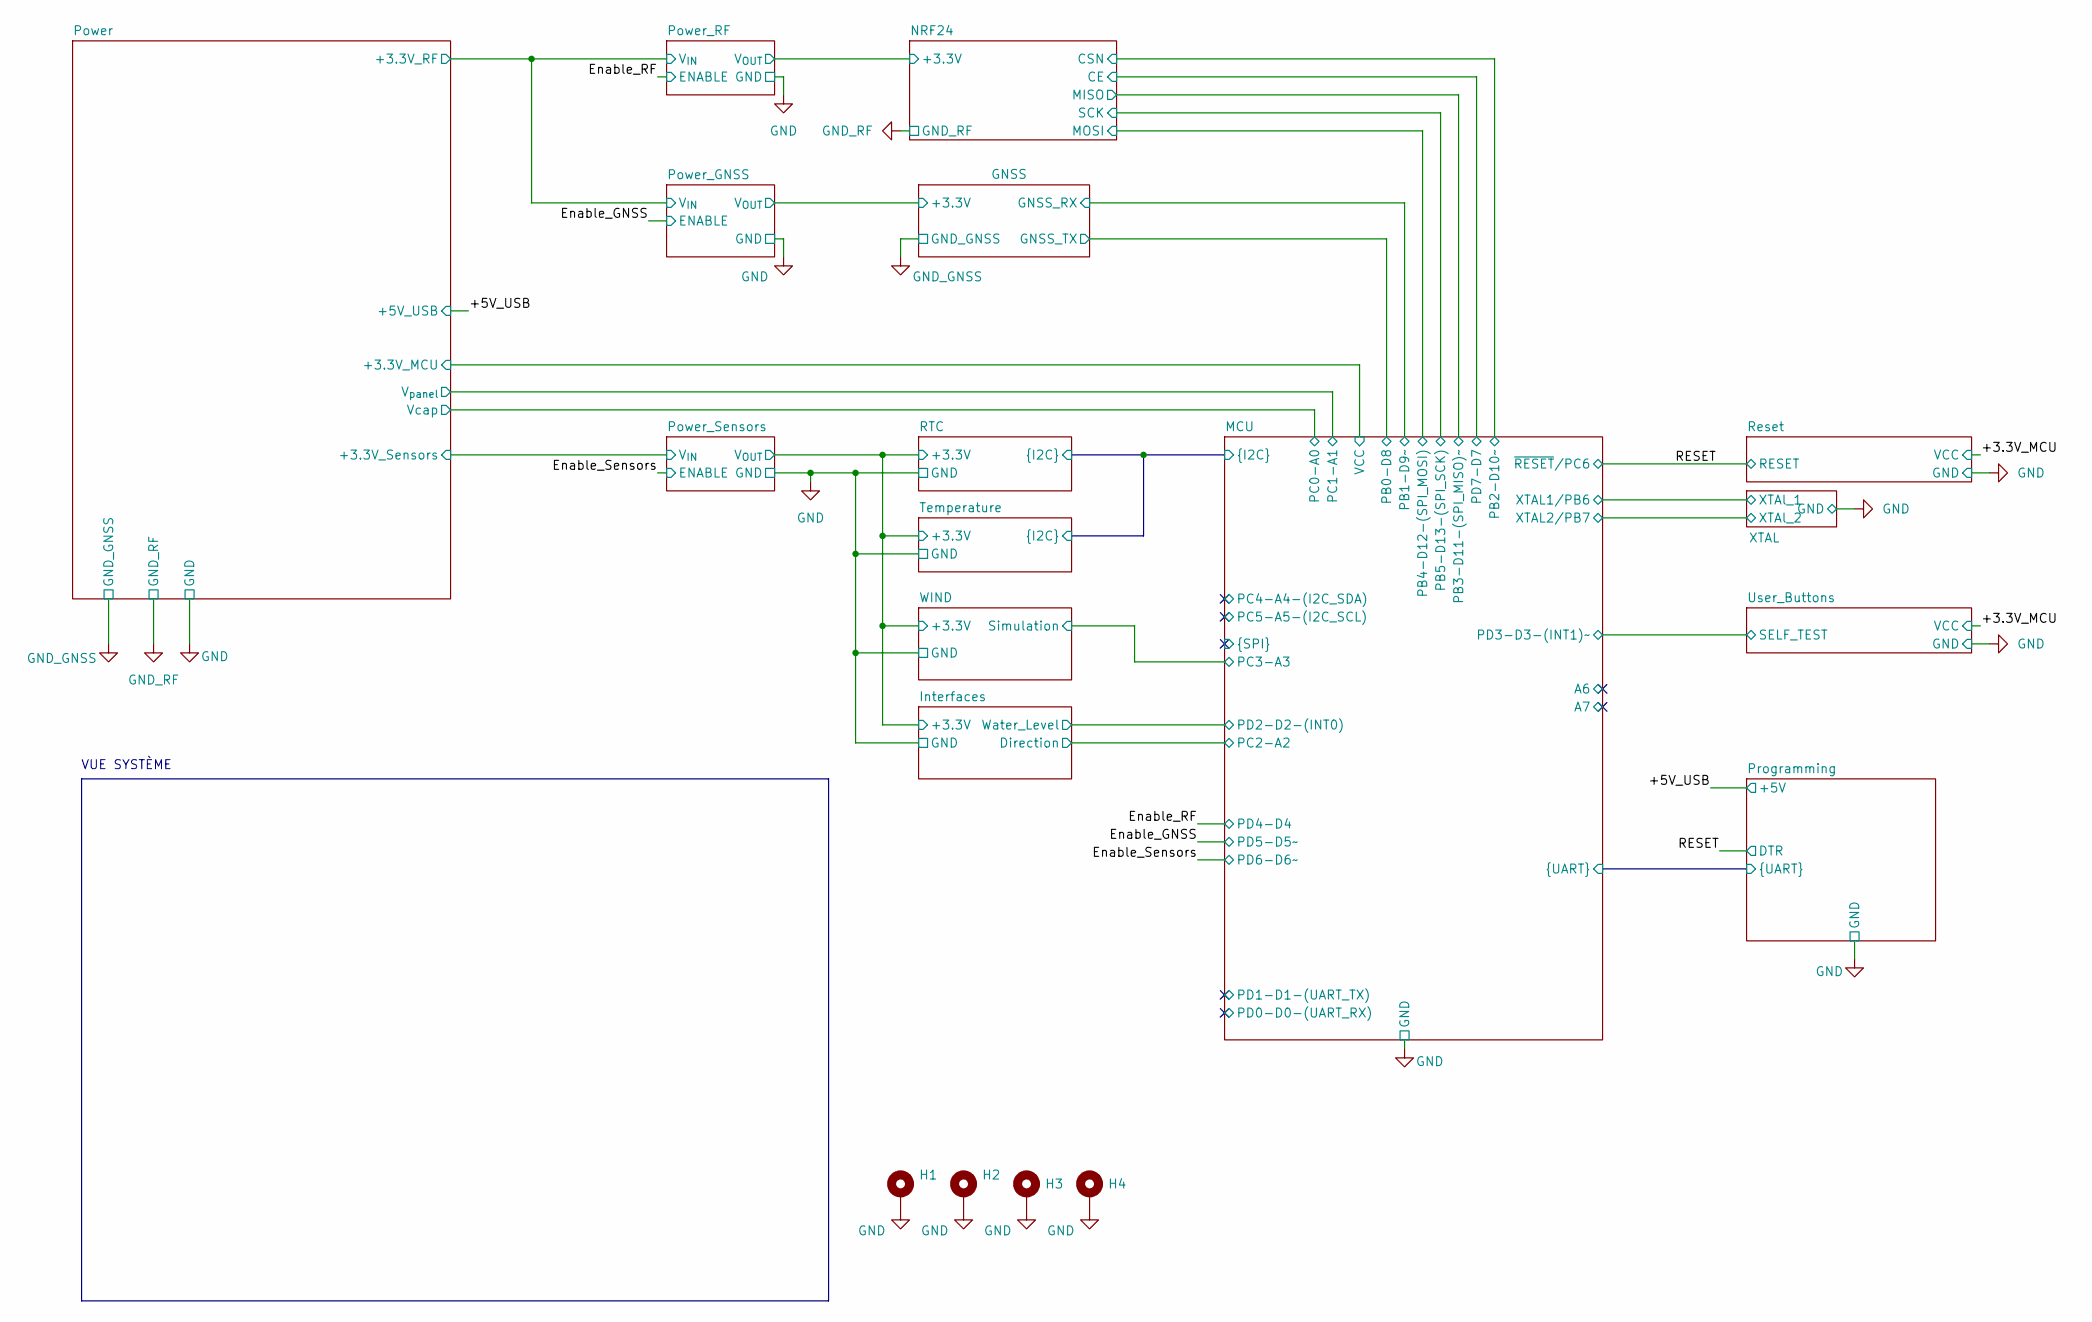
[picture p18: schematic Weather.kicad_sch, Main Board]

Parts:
H1, H2, H3, H4: MountingHole_Pad; MountingHole_3.2mm_M3

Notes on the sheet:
VUE SYSTÈME

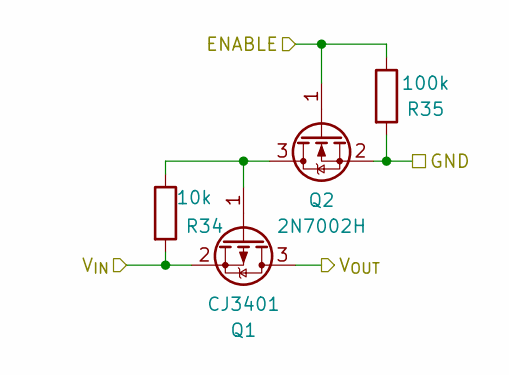
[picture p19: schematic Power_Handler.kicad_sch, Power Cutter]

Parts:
Q1: CJ3401; SOT-23
Q2: 2N7002H; SOT-23
R34: 10k; R_0603_1608Metric
R35: 100k; R_0603_1608Metric

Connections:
/Enable_GNSS: Q2.1 (G), R35.1; also elsewhere on the board
/GNSS/+3.3V: Q1.3 (D); also elsewhere on the board
/Power/+3.3V_RF: Q1.2 (S), R34.2; also elsewhere on the board
GND: Q2.2 (S), R35.2; also elsewhere on the board
unnamed: Q1.1 (G), Q2.3 (D), R34.1

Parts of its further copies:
Q3, Q5: CJ3401; SOT-23
Q4, Q6: 2N7002H; SOT-23
R7, R36: 10k; R_0603_1608Metric
R8, R37: 100k; R_0603_1608Metric

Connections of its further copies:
/Enable_RF: Q6.1 (G), R8.1; also elsewhere on the board
/Enable_Sensors: Q4.1 (G), R37.1; also elsewhere on the board
/Interfaces/+3.3V: Q3.3 (D); also elsewhere on the board
/NRF24/+3.3V: Q5.3 (D); also elsewhere on the board
/Power/+3.3V_RF: Q5.2 (S), R7.2; also elsewhere on the board
/Power/+3.3V_Sensors: Q3.2 (S), R36.2; also elsewhere on the board
GND: Q4.2 (S), Q6.2 (S), R8.2, R37.2; also elsewhere on the board
unnamed: Q3.1 (G), Q4.3 (D), R36.1
unnamed: Q5.1 (G), Q6.3 (D), R7.1


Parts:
C11, C12: 2.2uF; C_0603_1608Metric
C13, C14, C15, C16: 5F; C_Radial_D10.0mm_H20.0mm_P5.00mm
C17: 47uF; C_0603_1608Metric
C18: 100uF; CP_Elec_6.3x7.7
D3: SUN; LED_0603_1608Metric
D4: D_Zener; D_MiniMELF
D5, D6: SS24; D_SMA
J26: Panel; PhoenixContact_MSTBA_2,5_2-G-5,08_1x02_P5.08mm_Horizontal
J39: SolderJumper_2_Bridged; SolderJumper-2_P1.3mm_Bridged_Pad1.0x1.5mm
L2, L3, L6, L7: MPZ1608S101ATAH0; L_0603_1608Metric
L5: 33uH; L_Taiyo-Yuden_NR-50xx
R6, R20: 100; R_1206_3216Metric
R16: 390; R_0603_1608Metric
R17: 270; R_0603_1608Metric
R18: 0; R_0603_1608Metric
R19: 330; R_0603_1608Metric
T15, T16, T17, T18: TP; TestPoint_Pad_D1.0mm
U6: LM317_SOT-223; SOT-223-3_TabPin2
U7: BL8530; SOT-89-3

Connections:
/MCU/+VCC: L7.2; also elsewhere on the board
/MCU/PC0-A0: J39.2 (B); also elsewhere on the board
/Power/+3.3V: C18.1, D6.1 (K), R6.1, U7.2 (OUT); also elsewhere on the board
/Power/+3.3V_RF: L6.1, L7.1, R6.2, T18.1; also elsewhere on the board
/Power/+3.3V_Sensors: L6.2; also elsewhere on the board
GND: C11.1, C12.1, C13.2, C14.2, C15.2, C16.2, C17.1, C18.2, D3.1 (K), D4.2 (A), J26.2, L2.1, L3.1, R16.1, U7.1 (GND); also elsewhere on the board
GND_GNSS: L3.2; also elsewhere on the board
GND_RF: L2.2; also elsewhere on the board
unnamed 44: C11.2, J26.1, T15.1, U6.3 (VI); also elsewhere on the board
unnamed: D3.2 (A), R19.1
unnamed: C12.2, D4.1 (K), R17.2, R18.2, R20.1, T16.1, U6.2 (VO)
unnamed: D5.2 (A), R20.2
unnamed: C13.1, C14.1, C15.1, C16.1, C17.2, D5.1 (K), J39.1 (A), L5.1, T17.1
unnamed: D6.2 (A), L5.2, U7.3 (LX)
unnamed: R18.1, R19.2
unnamed: R16.2, R17.1, U6.1 (ADJ)

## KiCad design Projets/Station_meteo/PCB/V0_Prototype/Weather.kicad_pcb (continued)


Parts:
C3, C4, C5, C6: 100nF; C_0603_1608Metric
J24: Anemometer; PhoenixContact_MSTBA_2,5_2-G-5,08_1x02_P5.08mm_Horizontal
R3: 10k; R_0603_1608Metric
R4, R5: R_10K_SMD_0603; R_0603_1608Metric
T9, T10, T11: TP; TestPoint_Pad_D1.0mm
U2: LM358DR; TSSOP-8_4.4x3mm_P0.65mm
U3: 74HC123D; SOIC-16W_5.3x10.2mm_P1.27mm

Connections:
/Interfaces/+3.3V: C3.1, C5.1, R3.1, R4.1, U2.8 (V+), U3.16 (VCC); also elsewhere on the board
/MCU/PC3-A3: T9.1, U3.1 (A); also elsewhere on the board
GND: C3.2, C5.2, C6.2, J24.1, U2.4 (V-), U3.3 (Clr), U3.8 (GND); also elsewhere on the board
unnamed: J24.2, R3.2, U3.2 (B)
unnamed: C6.1, R5.2, U2.5 (+)
unnamed: T11.1, U2.6 (-), U2.7
unnamed: C4.2, U3.14 (Cext)
unnamed: R5.1, T10.1, U3.13 (Q)
unnamed: C4.1, R4.2, U3.15 (RCext)


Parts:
J32: Water_Level; PhoenixContact_MSTBA_2,5_2-G-5,08_1x02_P5.08mm_Horizontal
J35: Screw_Terminal_01x03; PhoenixContact_MSTBA_2,5_3-G-5,08_1x03_P5.08mm_Horizontal
R21: 100k; R_0603_1608Metric

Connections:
/Interfaces/+3.3V: J35.1, R21.1; also elsewhere on the board
/Interfaces/Direction: J35.2; also elsewhere on the board
/Interfaces/Water_Level: J32.1, R21.2; also elsewhere on the board
GND: J32.2, J35.3; also elsewhere on the board


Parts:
C9, C10: 22pF; C_0603_1608Metric
Y2: 16MHz; Crystal_SMD_HC49-SD

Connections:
/MCU/XTAL1/PB6: C9.2, Y2.2; also elsewhere on the board
/MCU/XTAL2/PB7: C10.2, Y2.1; also elsewhere on the board
GND: C9.1, C10.1; also elsewhere on the board


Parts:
C1, C2: 100nF; C_0603_1608Metric
J1, J2, J3, J4, J5, J6, J7, J8, J9, J10, J11, J12, J13, J14, J15, J16, J17, J18, J19, J20, J21, J22, J23: SolderJumper_2_Bridged; SolderJumper-2_P1.3mm_Bridged_Pad1.0x1.5mm
J31, J36, J37, J38: Conn_01x01_Pin; PinHeader_1x01_P2.54mm_Vertical
R1, R2: 4.7k; R_0603_1608Metric
T1, T2, T4, T5: TP; TestPoint_Pad_D1.0mm
U1: ATMEGA-328P; TQFP-32_7x7mm_P0.8mm

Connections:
/Enable_GNSS: J23.2 (B); also elsewhere on the board
/Enable_RF: J20.2 (B); also elsewhere on the board
/Enable_Sensors: J22.2 (B); also elsewhere on the board
/GNSS/GNSS_RX: J4.2 (B), T2.1; also elsewhere on the board
/Interfaces/Direction: J11.2 (B); also elsewhere on the board
/Interfaces/Water_Level: J18.2 (B); also elsewhere on the board
/MCU/+VCC: C1.2, C2.2, R1.1, R2.1, U1.4 (VCC), U1.6 (VCC), U1.18 (AVCC); also elsewhere on the board
/MCU/A6: J1.1 (A)
/MCU/A7: J2.1 (A)
/MCU/CLK: J8.2 (B), J37.1; also elsewhere on the board
/MCU/MISO: J7.2 (B), J36.1; also elsewhere on the board
/MCU/MOSI: J6.2 (B), J31.1; also elsewhere on the board
/MCU/PB0: J3.2 (B), T1.1; also elsewhere on the board
/MCU/PB2-D10~: J5.2 (B), J38.1; also elsewhere on the board
/MCU/PC0-A0: J9.2 (B); also elsewhere on the board
/MCU/PC1-A1: J10.2 (B); also elsewhere on the board
/MCU/PC3-A3: J12.2 (B); also elsewhere on the board
/MCU/PD3-D3-(INT1)~: J19.2 (B); also elsewhere on the board
/MCU/PD7-D7: J21.2 (B); also elsewhere on the board
/MCU/RX: J16.2 (B); also elsewhere on the board
/MCU/SCL: J14.2 (B), R2.2, T4.1; also elsewhere on the board
/MCU/SDA: J13.2 (B), R1.2, T5.1; also elsewhere on the board
/MCU/TX: J17.2 (B); also elsewhere on the board
/MCU/XTAL1/PB6: U1.7 (XTAL1/PB6); also elsewhere on the board
/MCU/XTAL2/PB7: U1.8 (XTAL2/PB7); also elsewhere on the board
/RESET: J15.2 (B); also elsewhere on the board
GND: C1.1, C2.1, U1.3 (GND), U1.5 (GND), U1.21 (GND); also elsewhere on the board
unnamed: J1.2 (B), U1.19 (ADC6)
unnamed: J2.2 (B), U1.22 (ADC7)
unnamed: J3.1 (A), U1.12 (PB0)
unnamed: J4.1 (A), U1.13 (PB1)
unnamed: J5.1 (A), U1.14 (PB2)
unnamed: J6.1 (A), U1.15 (PB3)
unnamed: J7.1 (A), U1.16 (PB4)
unnamed: J8.1 (A), U1.17 (PB5)
unnamed: J9.1 (A), U1.23 (PC0)
unnamed: J10.1 (A), U1.24 (PC1)
unnamed: J11.1 (A), U1.25 (PC2)
unnamed: J12.1 (A), U1.26 (PC3)
unnamed: J13.1 (A), U1.27 (PC4)
unnamed: J14.1 (A), U1.28 (PC5)
unnamed: J15.1 (A), U1.29 (~RESET/PC6)
unnamed: J16.1 (A), U1.30 (PD0)
unnamed: J17.1 (A), U1.31 (PD1)
unnamed: J18.1 (A), U1.32 (PD2)
unnamed: J19.1 (A), U1.1 (PD3)
unnamed: J20.1 (A), U1.2 (PD4)
unnamed: J21.1 (A), U1.11 (PD7)
unnamed: J22.1 (A), U1.10 (PD6)
unnamed: J23.1 (A), U1.9 (PD5)


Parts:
C8: 100nF; C_0603_1608Metric
D2: LED; LED_0603_1608Metric
R13: 0; R_0603_1608Metric
R14: 330; R_0603_1608Metric
T14: TP; TestPoint_Pad_D1.0mm
U13: DS3231M; SOIC-16W_7.5x10.3mm_P1.27mm

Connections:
/Interfaces/+3.3V: C8.1, D2.2 (A), U13.2 (VCC), U13.4 (~RST); also elsewhere on the board
/MCU/SCL: U13.16 (SCL); also elsewhere on the board
/MCU/SDA: U13.15 (SDA); also elsewhere on the board
GND: C8.2, U13.5 (GND), U13.6 (GND), U13.7 (GND), U13.8 (GND), U13.9 (GND), U13.10 (GND), U13.11 (GND), U13.12 (GND), U13.13 (GND); also elsewhere on the board
unnamed: D2.1 (K), R14.1
unnamed: R13.2, R14.2
unnamed: R13.1, T14.1, U13.3 (~INT/SQW)

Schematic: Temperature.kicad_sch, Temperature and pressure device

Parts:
J33: Screw_Terminal_01x04; PhoenixContact_MSTBA_2,5_4-G-5,08_1x04_P5.08mm_Horizontal

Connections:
/Interfaces/+3.3V: J33.1; also elsewhere on the board
/MCU/SCL: J33.2; also elsewhere on the board
/MCU/SDA: J33.3; also elsewhere on the board
GND: J33.4; also elsewhere on the board

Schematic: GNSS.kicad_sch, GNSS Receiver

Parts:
AE1: Internal_antenna; MountingHole_2.2mm_M2_DIN965_Pad
C26: 100nF; C_0603_1608Metric
C27: 120pF; C_0603_1608Metric
D7: GNSS; LED_0603_1608Metric
D8: POS_ENABLE; LED_0603_1608Metric
L8: MPZ1608S101ATAH0; L_0603_1608Metric
R22, R23, R24, R26: 0; R_0603_1608Metric
R25, R27: 330; R_0603_1608Metric
T19, T20: TP; TestPoint_Pad_D1.0mm
U9: NEO-M8M; ublox_NEO

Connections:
/GNSS/+3.3V: C26.2, L8.1, L8.2, R24.2, T20.1, U9.8 (~RESET), U9.23 (VCC); also elsewhere on the board
/GNSS/GNSS_RX: R23.1; also elsewhere on the board
/MCU/PB0: R22.1; also elsewhere on the board
GND_GNSS: C26.1, D7.1 (K), D8.1 (K), U9.10 (GND), U9.12 (GND), U9.13 (GND), U9.24 (GND); also elsewhere on the board
unnamed: AE1.1 (A), C27.1
unnamed: D7.2 (A), R25.1
unnamed: D8.2 (A), R27.1
unnamed: R24.1, R25.2
unnamed: R26.1, R27.2
unnamed: T19.1, U9.2 (D_SEL)
unnamed: C27.2, U9.11 (RF_IN)
unnamed: R23.2, U9.21 (RXD/SPI_MOSI)
unnamed: R26.2, U9.3 (TIMEPULSE)
unnamed: R22.2, U9.20 (TXD/SPI_MISO)

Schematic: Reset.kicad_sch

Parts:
J25: KF128-2.54_2P; TerminalBlock_Phoenix_MPT-0,5-2-2.54_1x02_P2.54mm_Horizontal
R15: 10k; R_0603_1608Metric
SW1: PB_SMD_12V_50MA_6MM_6MM; SW_Push_1P1T_NO_CK_KSC7xxJ

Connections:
/+3.3V_MCU: R15.1; also elsewhere on the board
/RESET: J25.1, R15.2, SW1.2 (B); also elsewhere on the board
GND: J25.2, SW1.1 (A); also elsewhere on the board

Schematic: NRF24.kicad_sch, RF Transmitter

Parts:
C19: 4.7uF; C_0603_1608Metric
C20, C21, C22: 100nF; C_0603_1608Metric
C23: 2.2nF; C_0603_1608Metric
C24: 4.7pF; C_0603_1608Metric
C25: 1.5pF; C_0603_1608Metric
J27: 132415; SMA_Molex_73251-1153_EdgeMount_Horizontal
L1, L10, L11: 8.2nH; L_0603_1608Metric
L9: MPZ1608S101ATAH0; L_0603_1608Metric
R9, R10, R11, R12, R31: 0; R_0603_1608Metric
R32: 22k; R_0603_1608Metric
U8: NRF24L01; QFN-20-1EP_4x4mm_P0.5mm_EP2.5x2.5mm

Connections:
/MCU/CLK: R11.1; also elsewhere on the board
/MCU/MISO: R9.1; also elsewhere on the board
/MCU/MOSI: R10.1; also elsewhere on the board
/MCU/PB2-D10~: R12.1; also elsewhere on the board
/MCU/PD7-D7: R31.1; also elsewhere on the board
/NRF24/+3.3V: C19.1, C20.1, C21.1, C22.1, L9.1, L9.2, U8.7 (VDD), U8.15 (VDD), U8.18 (VDD); also elsewhere on the board
/NRF24/XTAL1/XTAl_1: U8.10 (XC1); also elsewhere on the board
/NRF24/XTAL1/XTAl_2: U8.9 (XC2); also elsewhere on the board
GND_RF: C19.2, C20.2, C21.2, C22.2, C23.2, C24.2, J27.2 (Ext), R32.1, U8.8 (VSS), U8.14 (VSS), U8.17 (VSS), U8.20 (VSS); also elsewhere on the board
unnamed: C25.1, L10.2
unnamed: C25.2, J27.1 (In)
unnamed: L1.2, L10.1, L11.1, U8.12 (ANT1)
unnamed: L11.2, U8.13 (ANT2)
unnamed: R31.2, U8.1 (CE)
unnamed: R12.2, U8.2 (CSN)
unnamed: R32.2, U8.16 (IREF)
unnamed: R10.2, U8.5 (MISO)
unnamed: R9.2, U8.4 (MOSI)
unnamed: R11.2, U8.3 (SCK)
unnamed: C23.1, C24.1, L1.1, U8.11 (VDD_PA)

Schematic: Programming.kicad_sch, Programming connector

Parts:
C28, C29: 2.2uF; C_0603_1608Metric
C30: 100nF; C_0603_1608Metric
D9: LED_USB; LED_0603_1608Metric
J28, J34, J40: SolderJumper_2_Bridged; SolderJumper-2_P1.3mm_Bridged_Pad1.0x1.5mm
J29: USB_C_Receptacle_USB2.0_16P; USB_C_Receptacle_GCT_USB4085
R28, R29: 0; R_0603_1608Metric
R30: 270; R_0603_1608Metric
U10: USBLC6-2P6; SOT-666
U11: CH340G; SOIC-16_3.9x9.9mm_P1.27mm
U12: AMS1117-3.3; SOT-223-3_TabPin2
Y3: 12MHz; Crystal_SMD_HC49-SD

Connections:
/+5V_USB: C28.2, J29.A4 (VBUS), J29.A9 (VBUS), J29.B4 (VBUS), J29.B9 (VBUS), U10.5 (VBUS), U12.3 (VI); also elsewhere on the board
/MCU/RX: J28.2 (B); also elsewhere on the board
/MCU/TX: J34.2 (B); also elsewhere on the board
/Programming/+3.3V: C29.2, D9.2 (A), J40.2 (B), U11.16 (VCC), U12.2 (VO)
/Programming/D+: U10.1 (I/O1), U11.5 (UD+)
/Programming/D-: U10.3 (I/O2), U11.6 (UD-)
/RESET: C30.2; also elsewhere on the board
GND: C28.1, C29.1, J29.A1 (GND), J29.A12 (GND), J29.B1 (GND), J29.B12 (GND), J29.S1 (SHIELD), R30.2, U10.2 (GND), U11.1 (GND), U12.1 (GND); also elsewhere on the board
unnamed: D9.1 (K), R30.1
unnamed: J28.1 (A), U11.2 (TXD)
unnamed: J29.A6 (D+), J29.B6 (D+), R29.1
unnamed: J29.A7 (D-), J29.B7 (D-), R28.1
unnamed: J34.1 (A), U11.3 (RXD)
unnamed: J40.1 (A), U11.4 (V3)
unnamed: R28.2, U10.4 (I/O2)
unnamed: R29.2, U10.6 (I/O1)
unnamed: U11.7 (XI), Y3.1
unnamed: U11.8 (XO), Y3.2
unnamed: C30.1, U11.13 (~DTR)



Board: 2 copper layers, 103.1 x 79.5 mm, 172 parts (7 on the bottom side), 115 nets.

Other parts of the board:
C7, C31: 22pF; C_0603_1608Metric
D1: SS24; D_SMA
J30: KF128-2.54_2P; TerminalBlock_Phoenix_MPT-0,5-2-2.54_1x02_P2.54mm_Horizontal
J41, J42: Conn_01x01_Pin; PinHeader_1x01_P2.54mm_Vertical
R33: 10k; R_0603_1608Metric
R38, R39: 100k; R_0603_1608Metric
SW2: PB_SMD_12V_50MA_6MM_6MM; SW_Push_1P1T_NO_CK_KSC7xxJ
Y1: 16MHz; Crystal_SMD_HC49-SD

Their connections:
/+3.3V_MCU: R33.1; also elsewhere on the board
/+5V_USB: D1.2 (A); also elsewhere on the board
/MCU/PC1-A1: R38.2, R39.1; also elsewhere on the board
/MCU/PD3-D3-(INT1)~: J30.2, R33.2, SW2.2 (B); also elsewhere on the board
/NRF24/XTAL1/XTAl_1: C7.2, Y1.2; also elsewhere on the board
/NRF24/XTAL1/XTAl_2: C31.2, Y1.1; also elsewhere on the board
/Power/+3.3V: J41.1; also elsewhere on the board
/Power/+3.3V_RF: J42.1; also elsewhere on the board
GND: J30.1, R39.2, SW2.1 (A); also elsewhere on the board
GND_RF: C7.1, C31.1; also elsewhere on the board
unnamed 44: D1.1 (K), R38.1; also elsewhere on the board

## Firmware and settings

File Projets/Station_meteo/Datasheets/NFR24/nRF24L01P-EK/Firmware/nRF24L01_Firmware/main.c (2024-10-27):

 /** @file main.c
 *
 * @author Runar Kjellhaug
 *
 * @compiler This program has been tested with Keil C51 V7.50.
 *
 * @copyright
 * Copyright (c) 2005 Nordic Semiconductor. All Rights Reserved.
 *
 * The information contained herein is confidential property of Nordic Semiconductor. The use,
 * copying, transfer or disclosure of such information is prohibited except by express written
 * agreement with Nordic Semiconductor.
 * @endcopyright
 *
 * $Date: 3.03.06 10:52 $
 * $Revision: 60 $
 *
 */
//  Global defines & includes
#include <cygnal\c8051F320.h>
#include "include\defines.h"
#include "include\usb.h"
#include "include\fwupgrade.h"
#include "include\F320_FlashPrimitives.h"
#include "include\nRF_API.h"
#include "include\ADC.h"
#include "include\TestApp.h"
#include "include\LL_API.h"
#include "include\Protocol_API.h"

code const UINT FW  = FW_VERSION;                                     // Firmware version, const..

BYTE xdata RX_buffer[USB_RX_SIZE];                                    // Last packet received from host

BYTE xdata TX_buffer[USB_TX_SIZE];                                    // Next packet to sent to host

BYTE xdata TX_pload[TX_PLOAD_MAX_WIDTH];                              // TX payload buffer
BYTE xdata RX_pload[RX_PLOAD_MAX_WIDTH];                              // RX payload buffer

BYTE xdata Table_Ptr;                                                 // Pointer for Freq_table lookup
BYTE xdata Freq_table[FREQ_TABLE_SIZE] = {2,27,52,7,32,57,12,37,
                                         62,17,42,67,22,47,72,77};    // Freq Agility table, predefined

BYTE xdata Trans_Ctrl[TRANS_PARAMS];                                  // Transmission Control bytes
BYTE xdata Freq_agil[NUM_OF_PIPES];                                   // Freq Agility On/Off for pipe.n
BYTE xdata TX_Addr[TX_ADDR_WIDTH];                                    // TX address buffer
BYTE xdata RX_pload_length[NUM_OF_PIPES];                             // holds #of bytes for pipe 0..5
BYTE xdata TX_pload_width;                                            // TX payload width variable
BYTE xdata Freq_Agil_Status;                                          // Variable that holds status of frequency agility
BYTE xdata Freq_Agil_Pipe;

BYTE xdata Button_Mode = 0;
BYTE xdata Button;                                                    // Variable that holds button index for communication
BYTE xdata SW1_Released;

//Status bytes
BYTE USB_Rx_Comp = 0;                                                 // Indicates new USB frame received
BYTE SPI_Mode = 0;                                                    // Select between HW and SW SPI
BYTE Sweep_Mode = 0;                                                  // Sweep mode on/off
BYTE Com_Mode = 2;                                                    // Communication mode on/off
BYTE IRQ_Source = 0x00;                                               // Indicates IRQ source from nRF24L01
BYTE Sweep_Progress;
BYTE Test_Mode;
BYTE Agil_Timeout;
BYTE LinkStatus[2];                                                   // Link status array, status & channel
BYTE LinkStat,LastStat;
BYTE TX_Update;
BYTE RX_Timeout;
UINT Link_Loss_Delay;                                                 // Link Loss dalay variable
BYTE Link_Loss_Status;

BYTE RX_pipe;                                                         // store RX_FIFO pipe number
BYTE byte_ctr;

// Variables used for 'Sweep_Mode'
BYTE sw_low,sw_high,next_ch;
BYTE Sweep_Time_Ctr = 0;

BYTE Trans_Tmr,Trans_Tmr_Ctr = 0;                                     // Variables for trans timer comm mode
BYTE Timer_Mode;                                                      // Variable for timer mode
BYTE Try_Ctr;                                                         // Try Counter variable
BYTE Pipe_Length;                                                     // Current RX pipe length variable
UINT CPU_temp, RF_Vdd;
BYTE Led_Blink1,Led_Blink2,Led_Blink3,Led_Blink4;
BYTE T2_State;

//--------------------------------------------------------------------
// Main Routine
//--------------------------------------------------------------------
void main(void)
{
  CPU_Init();

  while (TRUE)
  {
#ifdef _TESTMODE_
    while (!USB_Rx_Comp)                                              // wait for USB command
    {
      if(!SW1) Test_TX();                                             // Goto TX mode
      if(!SW2) Test_RX();                                             // Goto RX mode
      if(USB_SW != 0x0f)                                              // Enable SW3 = CE if USB_ID <> 0.
      {
        if(!SW3)
        {
          CE_Pin(CE_HIGH);                                            // Hold CE high while SW3 is pressed.
        }
        else 
        {
          CE_Pin(CE_LOW);                                             // Hold CE low as long as SW3 is released.
        }
      }
    }
#else
    while(!USB_Rx_Comp)                                               // wait for USB command, and prosess other operations
    {
      if(IRQ_Source)                                                  // wait for nRF24L01 interrupt
      {
      EX0 = 0;                                                        // Disable External interrupt during prosessing
      if(T2_State)
        {
          ET2 = 0;                                                    // Disable T2 interrupt
          Stop_T2();                                                  // and stop timer2
        }
        switch(IRQ_Source)
        {
          case RX_DR:                                                 // RX Data received interrupt                                          
            do
            {
              RX_pipe = L01_Read_RX_Pload(RX_pload) >> 8;             // Read current payload
              if(Freq_Agil_Pipe == RX_pipe)                           // Packet received for "expected" pipe?
              {
                Blink_Led(LED1);                                      // _DEBUG_LED_ Led1 BLINK
                LinkStatus[LINK_STATUS] = LINK_ESTABLISH;             // Indicate "Link Loss"
                LinkStatus[LINK_CHANNEL] = L01_Get_Channel();         // Insert current channel
              
                LinkStat = LINK_ESTABLISH;                            // New LinkStat
                Agil_Timeout  = CLEARED;                              // Packet received, i.e. ok
                Trans_Tmr_Ctr = CLEAR;                                // Reset frequency agility timer
              }
              else
                Blink_Led(LED2);                                      // _DEBUG_LED_ Led2 BLINK if data of other pipe
            }
            while(!(L01_Get_FIFO() & RX_EMPTY));                      // ..until FIFO empty

            L01_Clear_IRQ(MASK_RX_DR_FLAG);                           // clear RX_DR flag
          break;
          
          case TX_DS:                                                 // TX Data sent interrupt
            Blink_Led(LED1);                                          // _DEBUG_LED_ Led1 BLINK
            LinkStat = LINK_ESTABLISH;                                // set LinkStat = LINK_ESTABLISH
            Trans_Tmr_Ctr = CLEAR;                                    // reset Transmitt Timer..

            L01_Clear_IRQ(MASK_TX_DS_FLAG);                           // Clear TX_DS flag
          break;

          case MAX_RT:
          {
            Blink_Led(LED3);                                          // _DEBUG_LED_ Led3 BLINK

            if(Freq_Agil_Status)                                      // running in freq_agil mode?
            {
              if(++Table_Ptr == FREQ_TABLE_SIZE)                      // Freq_table wrapping?
              {
                Blink_Led(LED4);                                      // _DEBUG_LED_ Led4 BLINK
                Table_Ptr = CLEAR;                                    // Reset Table_Ptr to first channel,
                if(Try_Ctr++ == 3)
                {
                  LinkStat = STOP;
                }
              }
              L01_Set_Channel(Freq_table[Table_Ptr]);                 // select new channel
            }
            
            Trans_Tmr_Ctr = CLEAR;                                    // reset Transmitt Timer..
            switch(LinkStat)
            {
              case LINK_ESTABLISH:                                    // max retransmitt, but had comm on last channel
                L01_Clear_IRQ(MASK_MAX_RT_FLAG);                      // clear MAX_RT flag (nRF24L01)
              
                LinkStat = LINK_LOSS;                                 // change LinkStat state to LINK_LOSS, wait for new timeout
              break;

              case LINK_LOSS:                                         // still not connected, run channel scan..
                L01_Clear_IRQ(MASK_MAX_RT_FLAG);                      // clear MAX_RT flag (nRF24L01)
                CE_Pin(CE_PULSE);                                     // retransmitt packet
              
                LinkStat = LINK_RELOST;                               // change LinkStat state to LINK_RELOST
              break;
            
              case LINK_RELOST:
                L01_Clear_IRQ(MASK_MAX_RT_FLAG);                      // clear MAX_RT flag (nRF24L01)
                CE_Pin(CE_PULSE);                                     // retransmitt packet
              
                LinkStat = LINK_RELOST;
              break;

              case STOP:
                L01_Clear_IRQ(MASK_MAX_RT_FLAG);                      // clear MAX_RT flag
                LinkStat = LINK_ESTABLISH;                            // stop retransmission
              break;
            }
          }
          break;

          default:                                                    // ..error handler
          
          break;
        }
        IRQ_Source = CLEAR;                                           // Clear IRQ flag

        if(T2_State)
          {
            Start_T2();
            ET2 = 1;                                                  // Enable T2 interrupt only if T2 in use          
          }

        EX0 = 1;                                                      // Enable external interrupt again..
      }
      
      Check_Button_TX();

    }


#endif
    Sweep_Mode = CLEAR;                                               // Terminate Sweep_Mode
    USB_Rx_Comp = CLEAR;
    switch(RX_buffer[CMD])                                            // USB command decoder
    {
      case CSN_STATE:                                                 // Set/Reset CSN(NSS) pin
        CSN_Pin(RX_buffer[ARG]);
        TX_buffer[0] = 0;
        Block_Write(TX_buffer,1);
      break;

      case SPI_COMMAND:                                               // Writes a SPI byte
        TX_buffer[0] = SPI_RW(RX_buffer[ARG]);
        Block_Write(TX_buffer,1);
      break;

      case CE_BIT:                                                    // Set/Reset CE pin
        CE_Pin(RX_buffer[ARG]);
        
        TX_buffer[0] = 0;
        Block_Write(TX_buffer,1);
      break;

      case FW_VER:                                                    // Return current FirmWare version
        TX_buffer[0] = (BYTE)(FW>>8);                                 // Get major FW_Ver
        TX_buffer[1] = (FW & 0xff);                                   // Get minor FW_Ver
        
        Block_Write(TX_buffer, 2);
      break;

      case READ_USB_ID:                                               // Return current USB_ID switch setting
        TX_buffer[0] = USB_ID;                                        // macro; defines.h
        Block_Write(TX_buffer,1);
      break;

      case WRITE_LEDS:                                                // Set/Reset LED...
        Write_Led(RX_buffer[ARG], RX_buffer[VALUE]);
        TX_buffer[0] = 0;
        Block_Write(TX_buffer,1);
      break;

      case WR_FLASH_BLOCK:                                            // Writes 32 bytes of flash data to block 'n'
        WritePageBlock(RX_buffer[ARG], &RX_buffer[VALUE]);
        TX_buffer[0] = 0x00;
        Block_Write(TX_buffer,1);
      break;

      case RD_FLASH_BLOCK:                                            // Reads and return 32 bytes of flash block 'n'
        ReadPageBlock(RX_buffer[ARG], &TX_buffer[0]);
        Block_Write(TX_buffer, SZ_BLOCK);
      break;

      case WR_FLASH_PAGE:                                             // Writes the flash page n*256 buffer to flash
        if (RX_buffer[ARG] == 0)
          EA = 0;
        WriteFlashPage((unsigned)RX_buffer[ARG]);
        if (RX_buffer[ARG] == 0)
          EA = 1;

        TX_buffer[0] = 0x00;
        Block_Write(TX_buffer,1);
      break;

      case RD_FLASH_PAGE:                                             // Read the n*256 flash page to flash buffer
        ReadFlashPage((unsigned)RX_buffer[ARG]);
        TX_buffer[0] = 0x00;
        Block_Write(TX_buffer,1);
      break;

      case WD_RESET:                                                  // Use WatchDog reset to reset F320
        WD_Reset();
      break;

      case READ_LOCK_BYTE:                                            // Return Lock Byte
        TX_buffer[0] = FLASH_ByteRead(0x3dff);
        Block_Write(TX_buffer, 1);
      break;

      case SPI_SELECT:                                                // Select SPI Mode
        SPI_Init(RX_buffer[ARG]);
        TX_buffer[0] = 0;
        Block_Write(TX_buffer,1);
      break;

      case ST_FR_SWEEP_TX:                                            // Start Frequency Sweep TX[sw_low..sw_high]
        sw_high = RX_buffer[1];
        sw_low  = RX_buffer[2];
        next_ch = sw_low;                                             // Init sweep low channel
        Sweep_Mode = 1;                                               // Sweep_Mode on.
        Sweep_Progress = 1;                                           // Indicates sweep in progress
        ET2 = 1;                                                      // Enable Timer2
        TX_buffer[0] = 0;
        Block_Write(TX_buffer,1);
      break;

      case ST_FR_SWEEP_RX:                                            // Start Frequency Sweep RX[sw_low..sw_high]
        sw_high = RX_buffer[1];
        sw_low  = RX_buffer[2];
        next_ch = sw_low;                                             // init sweep low channel
        Sweep_Mode = 1;                                               // Sweep_Mode on.
        Sweep_Progress = 1;                                           // Indicates sweep in progress
        ET2 = 1;                                                      // Enable Timer2
        TX_buffer[0] = 0;
        Block_Write(TX_buffer,1);
      break;

      case STOP_SWEEP:                                                // Stop current frequency sweep
        Sweep_Mode = 0;                                               // Terminate Sweep_Mode

        TX_buffer[0] = 0;
        Block_Write(TX_buffer,1);
      break;

      case WR_TRANS_CTRL:                                             // Set TX control parameters
        Trans_Ctrl[0] = RX_buffer[ARG];
        Trans_Ctrl[1] = RX_buffer[VALUE];

        TX_buffer[0] = 0;
        Block_Write(TX_buffer,1);
      break;

      case RD_TRANS_CTRL:                                             // Return TX control parameters
        TX_buffer[0] = Trans_Ctrl[0];
        TX_buffer[1] = Trans_Ctrl[1];
        Block_Write(TX_buffer,2);
      break;

      case WR_FREQ_AGIL:                                              // Set freq. agility parameters to pipe.n variabel
        Freq_agil[RX_buffer[ARG]] = RX_buffer[VALUE];

        TX_buffer[0] = 0;
        Block_Write(TX_buffer,1);
      break;

      case RD_FREQ_AGIL:                                              // Return freq.agility parameters for pipe.n
        TX_buffer[0] = Freq_agil[RX_buffer[ARG]];
        Block_Write(TX_buffer,1);
      break;

      case WR_CH_TABLE:                                               // Write freq_table contents
        for(byte_ctr=0;byte_ctr<FREQ_TABLE_SIZE;byte_ctr++)
          Freq_table[byte_ctr] = RX_buffer[ARG + byte_ctr];

        TX_buffer[0] = 0;
        Block_Write(TX_buffer,1);
      break;

      case RD_CH_TABLE:                                               // Read freq_table data
        for(byte_ctr=0;byte_ctr<FREQ_TABLE_SIZE;byte_ctr++)
          TX_buffer[byte_ctr] = Freq_table[byte_ctr];

        Block_Write(TX_buffer,FREQ_TABLE_SIZE);
      break;

      case WR_TX_PAYLOAD:                                             // Write TX payload data
        for(byte_ctr=0;byte_ctr<RX_buffer[ARG];byte_ctr++)
          TX_pload[byte_ctr] = RX_buffer[(byte_ctr+2)];               // Load TX payload into buffer
        TX_pload_width = RX_buffer[ARG];                              // Write TX_pload witdh

        TX_buffer[0] = 0;
        Block_Write(TX_buffer,1);
      break;

      case READ_TX_PLOAD:                                             // Host read TX payload
        TX_buffer[0] = TX_pload_width;
        for(byte_ctr=0;byte_ctr < TX_pload_width;byte_ctr++)
          TX_buffer[byte_ctr+1] = TX_pload[byte_ctr];                 // Load TX_buffer with TX payload data

        Block_Write(TX_buffer, (TX_pload_width + 1));
      break;
      
      case WR_RX_PLOAD_LENGTH:                                        // Write RX payload length for pipe.n
        RX_pload_length[RX_buffer[ARG]] = RX_buffer[VALUE];
        
        TX_buffer[0] = 0;
        Block_Write(TX_buffer, 1);
      break;

      case RD_RX_PLOAD_LENGTH:                                        // Read RX payload length for pipe.n
        TX_buffer[0] = RX_pload_length[RX_buffer[ARG]];

        Block_Write(TX_buffer, 1);
      break;

      case START_COM_MODE:                                            // Start communication mode
        Com_Mode = RX_buffer[ARG];
        TX_buffer[0] = 0;
        Block_Write(TX_buffer,1);

        Start_Communication(Com_Mode);
      break;

      case READ_TEMP:                                                 // Read C8051F320 temperature
        CPU_temp = Read_Temperature();
        TX_buffer[0] = (CPU_temp >> 8);
        TX_buffer[1] = (CPU_temp & 0xff);
        Block_Write(TX_buffer,2);
      break;

      case READ_VOLT:                                                 // Read RF_Vdd voltage
        RF_Vdd = Read_RF_Vdd();
        TX_buffer[0] = (RF_Vdd >> 8);
        TX_buffer[1] = (RF_Vdd & 0xff);
        Block_Write(TX_buffer,2);
      break;

      case READ_RX_DATA:                                              // Read RX data
      break;

      case ENTER_TEST_MODE:                                           // Enter testmode
        Enter_Testmode(RX_buffer[ARG]);
        TX_buffer[0] = 0;
        Block_Write(TX_buffer,1);
      break;

      case WR_FREQ_AGILITY:                                           // Enable/ disable freq.agility
        Freq_Agil_Status = RX_buffer[ARG];

        TX_buffer[0] = 0;
        Block_Write(TX_buffer, 1);
      break;

      case RD_FREQ_AGILITY:                                           // Read freq.agility status (enabled or disabled)
        TX_buffer[0] = Freq_Agil_Status;
        Block_Write(TX_buffer, 1);
      break;

      case UPDATE_DEVICE:                                             // Command that indicates a new device update
//        Reset_L01();                                                  // Reset L01 before new update, NOT implemented
        TX_buffer[0] = 0;
        Block_Write(TX_buffer, 1);
      break;

      case STOP_COMM_MODE:                                            // Command received when "Stop Comm.. Mode" button pressed..
        IRQ_Source = CLEAR;
        ET2 = 0;                                                      // Disable T2 interrupt
        EX0 = 0;                                                      // Disable extern interrupt0, nRF24L01_IRQ
        CE_Pin(CE_LOW);                                               // CE low
        Led1 = Led2 = Led3 = Led4 = 1;                                // Clear all status Led's
        Com_Mode = 2;                                                 // Set Com_Mode = 2, idle
        
        TX_buffer[0] = 0;
        Block_Write(TX_buffer, 1);
      break;

      case RD_COMM_MODE_STAT:                                         // Return communication mode status
        TX_buffer[0] = Com_Mode;
        Block_Write(TX_buffer, 1);
      break;

      case RD_LINK_STATUS:                                            // Return Link Status to host
        TX_buffer[0] = LinkStatus[0];
        TX_buffer[1] = LinkStatus[1];
        LinkStatus[0] = LinkStatus[1] = 0;                            // Clear status after status read
        Block_Write(TX_buffer, 2);
      break;

      default:                                                        // Default switch() handler
      break;
    }

  }

}


/*********************************************
*
* Start_Communication
*
* Starts either RX or TX mode
*
*********************************************/
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

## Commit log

2024-10-27 Add diagramm
    [132255.stp, 8967560.stp, AVR_ISP_2R5W_254P.STEP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]
2024-11-03 Add schematic and PCBA
    [132255.stp, 8967560.stp, AVR_ISP_2R5W_254P.STEP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]
2024-11-04 Update PCB
    [Crystal.kicad_sch, Interfaces.kicad_sch, MCU.kicad_sch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]
2024-11-11 Add V1 THT version
    [132255.stp, 8967560.stp, AVR_ISP_2R5W_254P.STEP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]
2024-11-30 Update PCB_V1
    [132255.stp, 8967560.stp, AVR_ISP_2R5W_254P.STEP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]
2024-12-19 Add shields
    [Base.kicad_pcb, Base.kicad_sch, Lithium.kicad_pcb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]
2025-01-19 update of directory
    [Base.kicad_pcb, Power.kicad_sch, Shield_Lithium.kicad_sch]
2025-01-21 Update PCB Base
    [Anemometer.kicad_sch, Anemometer1.kicad_sch, Base.kicad_pcb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]
2025-01-26 Update Weather station
    [Base.kicad_pcb, Base.kicad_sch, Bridge.kicad_sch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]
2025-02-21 Update Base
    [Base.kicad_pcb, MCU.kicad_sch, Reset.kicad_sch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]
2025-03-15 Update Schematic
    [Base.kicad_pcb, Base.kicad_sch, GNSS.kicad_sch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]
